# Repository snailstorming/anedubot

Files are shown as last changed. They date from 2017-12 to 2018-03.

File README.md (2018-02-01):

# anedubot
Another educational robot

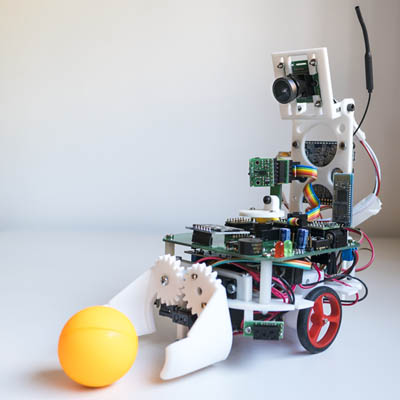
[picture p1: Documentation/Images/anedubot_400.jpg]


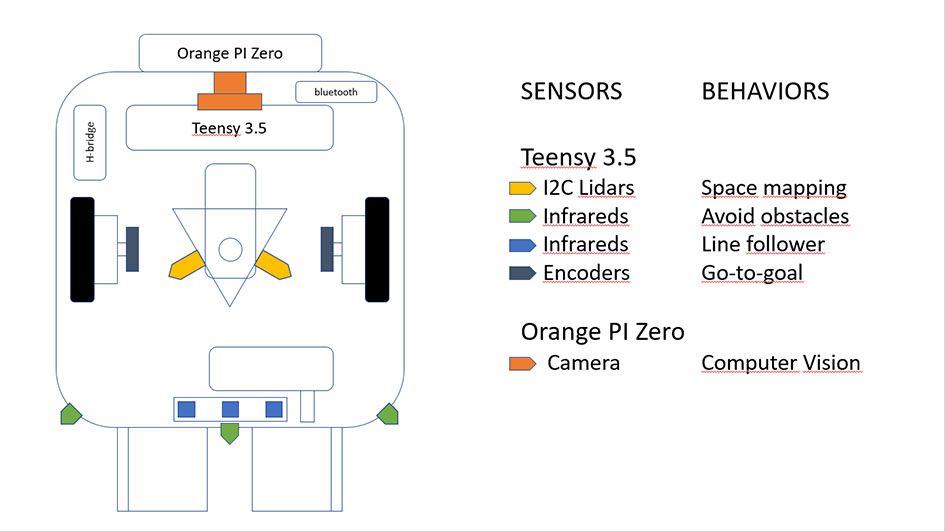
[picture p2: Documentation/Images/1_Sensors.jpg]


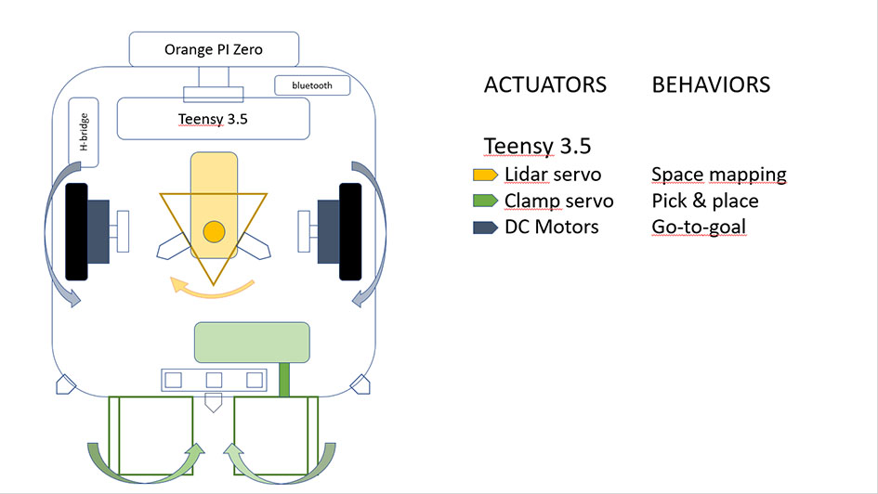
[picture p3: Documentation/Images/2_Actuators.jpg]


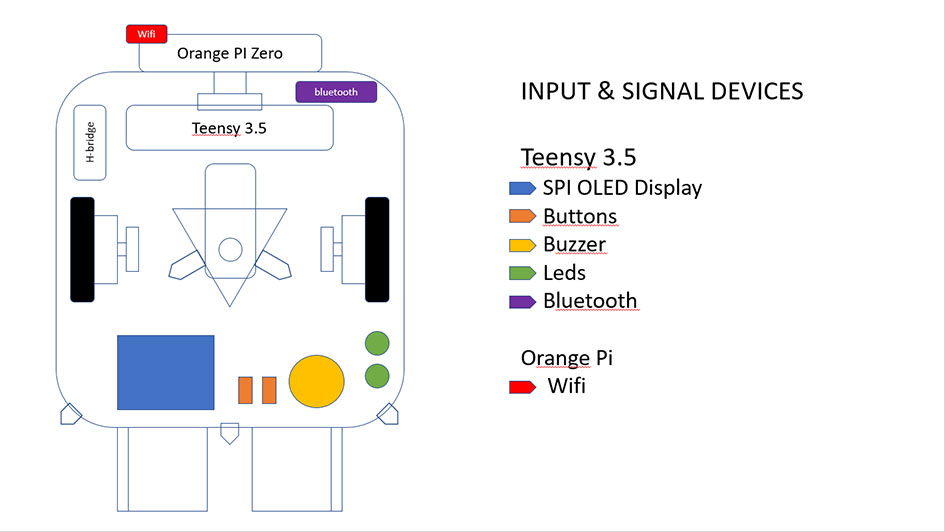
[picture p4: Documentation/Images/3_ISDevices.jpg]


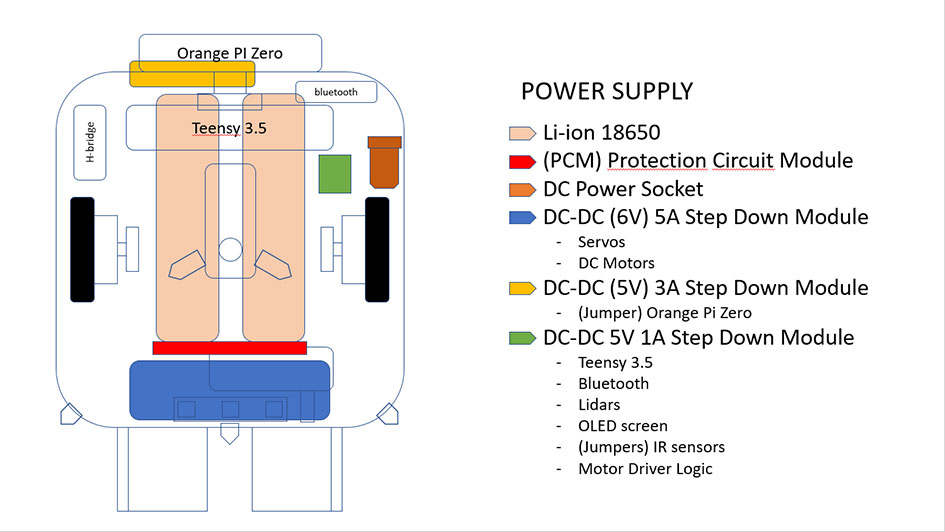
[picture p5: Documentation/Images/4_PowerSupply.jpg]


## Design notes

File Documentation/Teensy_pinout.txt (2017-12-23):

// BUZZER AND RED LED
#define BUZZER_RED_LED  22

//LIDAR SERVO
#define LIDAR_SERVO  8

//CLAMP SERVO
#define CLAMP_SERVO  8

// SPI OLED SCREEN
#define OLED_MOSI   24
#define OLED_CLK   	10
#define OLED_DC    	11
#define OLED_CS    	12
#define OLED_RESET 	25

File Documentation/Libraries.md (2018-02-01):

# EDIT Adafruit_SSD1306 library:
C:\Program Files (x86)\Arduino\hardware\teensy\avr\libraries\Adafruit_SSD1306
```c
   #define SSD1306_128_64
//   #define SSD1306_128_32
//   #define SSD1306_96_16
```

# LIDAR:

[https://github.com/pololu/vl53l0x-arduino](https://github.com/pololu/vl53l0x-arduino)

# MOTORS:

[https://github.com/kevinwchang/r2-dr](https://github.com/kevinwchang/r2-dr)

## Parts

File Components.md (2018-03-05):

Basic model with magnetic encoders:

| ID | Quantity | Description | Link | Price |
|---|---|---|---|---|
|---|---| **Power Supply** |---|---|
| 01 | 2  | 3.7V 18650 Lithium-ion Battery | [RS-AMIDATA](https://ie.rs-online.com/web/p/speciality-size-rechargeable-batteries/7887261/) | 17.18 € |
| 02 | 1 | Battery holder with PCM | [Fasttech](https://www.fasttech.com/p/1279500) | 4 € |
| 03 | 1 | DC-DC 5A Step Down Converter Module | [aliexpress](https://www.aliexpress.com/item/DC-DC-4-5-30V-to-0-8-30V-5A-Step-Down-Converter-Module-Circuit-Voltage/1724909910.html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,searchweb201602_5_10152_10151_10065_10344_10068_10342_10547_10343_51102_10340_10548_10341_10084_10083_10307_10301_10303_10312_10313_10059_10314_10184_10534_100031_10604_10103_10605_10594_10142,searchweb201603_1,ppcSwitch_5&algo_expid=59acf9db-747c-4bae-9396-6da0b7c3cc02-29&algo_pvid=59acf9db-747c-4bae-9396-6da0b7c3cc02&rmStoreLevelAB=5) or [es.aliexpress](https://es.aliexpress.com/item/DC-DC-4-5V-30V-to-0-8V-30V-5A-Step-Down-Power-Apply/32332363457.html) | 4.5€ |
| 04 | 1 | PCB Mount 5.5x2.1mm DC Power Jack Socket | [aliexpress](https://es.aliexpress.com/store/product/10Pcs-PCB-Mount-5-5-x-2-1-mm-Female-DC-Power-Jack-Plug-Socket-Connector/2881256_32816199401.html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,searchweb201602_5_10152_10151_10065_10344_10068_10342_10547_10343_51102_10340_10548_10341_10084_10083_10307_10301_10303_10312_10313_10059_10314_10184_10534_100031_10604_10103_10605_10594_10142,searchweb201603_1,ppcSwitch_5&algo_expid=5eab03d4-3ff3-4e66-bbec-f828e346cfb2-0&algo_pvid=5eab03d4-3ff3-4e66-bbec-f828e346cfb2&rmStoreLevelAB=5) | 1.02 € |
| 05 | 1 | 5.5mm 2.1mm DC 8.4V 1A Power Adapter Supply | [Fasttech](https://www.fasttech.com/p/1284905) | 4 € |
| 06 | 1 | 5V step-up/step-down voltage regulator | [EXP-TECH](https://www.exp-tech.de/en/modules/currentvoltage/4823/pololu-5v-step-up/step-down-voltage-regulator-s7v7f5) | 5€ |
| 07 | 1 | 3.5mm Pitch Terminal Block | [EXP-TECH](https://ie.rs-online.com/web/p/pcb-terminal-blocks/7100444/) | 1.5 €|
|---|---|---|---|---|
| 08 | 1 | Teensy 3.5 | [EXP-TECH](https://www.exp-tech.de/en/platforms/teensy/7786/teensy-3.5) | 25.95 € |
| 09 | 1 | Bluetooth module | [DX](http://www.dx.com/p/jy-mcu-arduino-bluetooth-wireless-serial-port-module-104299) | 4.41 € |
| 10 | 1 | SPI I2C OLED screen | [EBAY](https://www.ebay.com/itm/0-96-I2C-IIC-SPI-Serial-128X64-White-OLED-LCD-LED-Display-Module-for-Arduino-/182546048967) | 3 € |
|---|---| **hardware parts** |---|---|
| 11 | 4 | M2x5 screws (for battery holder) |  |  |
| 12 | 4 | M2 nuts (for battery holder) |  |  |
| 13 | 4 | spacer M3x25 (for main structure) |  |  |
| 14 | 4 | M3x5 screw (for main structure) |  |  |
| 15 | 4 | M3 nuts (for main structure)|  |  |
| 16 | 2 | 12mm Chrome Steel Steel Ball Bearings (for main structure)|  |  | 
|---|---| **Motor parts** |---|---|
| 17 | 2 | mini plastic gearmotor | [EXP-TECH](https://www.exp-tech.de/en/motors/dc-gearmotors/7707/120-1-mini-plastic-gearmotor-hp-offset-3mm-d-shaft-output-extended-motor-shaft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) | 13 € |
| 18 | 1 | magnetic encoders | [EXP-TECH](https://www.exp-tech.de/en/sensors/magnet/7899/magnetic-encoder-pair-kit-for-20d-mm-metal-gearmotors-20-cpr-2.7-18v) | 10 € |
| 19 | 1 | 40mm Wheel | [EXP-TECH](https://www.exp-tech.de/en/accessories/mechanical-components/7847/pololu-wheel-40x7mm-pair-red) | 5.5 € |
| 20 | 1 | Gearmotor bracket | [EXP-TECH](https://www.exp-tech.de/en/motors/dc-gearmotors/6288/pololu-mini-plastic-gearmotor-bracket-pair-wide) | 4.5 € |
| 21 | 1 | motor driver | [EXP-TECH](https://www.exp-tech.de/en/modules/motor-controllers/dc-motors/4805/pololu-drv8835-dual-motor-driver-carrier) | 4.20 € |
|---|---| **Pin headers** |---|---|
| 22 | 1 | Pin headers | [EXP-TECH](https://www.exp-tech.de/en/accessories/connectors/7921/1x40-pin-break-away-headers-straight-10-pack) | 5 € |
| 23 | 1 | Short pin headers | [EXP-TECH](https://www.exp-tech.de/en/accessories/connectors/6759/2mm-pitch-40-pin-break-apart-male-headers-pack-of-5) | 3.5 € |
| 24 | 1 | Short female socket headers | [EXP-TECH](https://www.exp-tech.de/en/accessories/connectors/6760/2mm-pitch-25-pin-female-socket-headers-pack-of-5) | 4 € |
| 25 | 1 | 1x4 female socket headers | [RS-AMIDATA](https://ie.rs-online.com/web/p/pcb-sockets/8282067/) | 1 € |
|---|---| Other parts |---|---|
| 26 | 1 | red led | [RS_AMIDATA](https://ie.rs-online.com/web/p/visible-leds/2285988/) | 1.3 € |
| 27 | 1 | green led | [RS_AMIDATA](https://ie.rs-online.com/web/p/visible-leds/2286004/) | 1.3 € |
| 28 | 1 | Piezo buzzer | [RS-AMIDATA](https://ie.rs-online.com/web/p/piezo-buzzer-components/5358253/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) | 2.5 € |
| 29 | 1 | resitor 220ohms | [RS-AIMDATA](https://ie.rs-online.com/web/p/through-hole-fixed-resistors/7077612/) | 1.5 €|
| 30 | 1 | resitor 22Kohms | [RS-AIMDATA](https://ie.rs-online.com/web/p/through-hole-fixed-resistors/7077779/) | 1.5 €|
| 31 | 1 | jumpers | [RS-AMIDATA](https://ie.rs-online.com/web/p/jumpers-shunts/6742397/) | 1 € |
| 32 | 1 | mini pushbutton switch | [RS-AMIDATA](https://www.exp-tech.de/en/accessories/buttonsswitches/5434/mini-pushbutton-switch-pcb-mount-2-pin-spst-50ma-5-pack) | 1 € |
| 33 | 1 | Slide Switch | [RS-AMIDATA](https://www.exp-tech.de/en/accessories/buttonsswitches/5114/breadboard-friendly-spdt-slide-switch) | 1.5 € |
| 34 | 1 | Capacitor 100uF | [RS-AMIDATA](https://ie.rs-online.com/web/p/aluminium-capacitors/7110842/) | 2 € |
|---|---| **PCB** |---|---|
| 35 | 1 | PCB|[PCB Way](https://www.pcbway.com/)| 15€|
|---|---| **3D Frame** |---|---|
| 36 | 1 | Base.scad |[3DHUBS](https://www.3dhubs.com)| 12€|
|---|---| **Total price** |---|---|
|---|---|---|---| **163 €** |

Pick & place Kit:

| ID | Quantity | Description | Link | Price |
|---|---|---|---|---|
| 37 | 1 | Servo motor | [EBAY](https://www.ebay.com/itm/232208650170) | 6 € |
|---|---| ***3D Frame*** |---|---|
| 38 | 1 | Clamp |[3DHUBS](https://www.3dhubs.com)|  € |
| 39 | 1 | Clamp_servo_support |[3DHUBS](https://www.3dhubs.com)| 8 € |
|---|---| ***hardware parts*** |---|---|
| 40 | 2 | M3x20 screw (for servo bracket) |  |  |
| 41 | 2 | M3x10 screw (for servo) |  |  |
| 42 | 1 | M3x12 screw (for right clamp) |  |  |
| 43 | 2 | 2x8 wood screws (for left clamp) |  |  |
| 44 | 4 | M3 nuts |  |  |
|---|---| ***Balls*** |---|---|
| 45 | ? | colored ping pong balls |  |  |
| 46 | 3 | 12mm Chrome Steel Steel Ball Bearings (for main structure)|  |  |

Avoid Obstacles & Line Follower Kit:

| ID | Quantity | Description | Link | Price |
|---|---|---|---|---|
| 47 | 1 | Female-Male Jumper Wires | [EXP-TECH](https://www.exp-tech.de/en/accessories/cables/jumper-wires/7797/premium-female/male-extension-jumper-wires-40-x-6-150mm) | 4.5 € |
| 48 | 5 | M2x5 screw  |  |  |
| Avoid Obstacles |---|---|---|
| 49 | 2 | Digital Distance Sensor 5cm | [EXP-TECH](https://www.exp-tech.de/en/sensors/distanceapproximation/4905/pololu-carrier-with-sharp-gp2y0d805z0f-digital-distance-sensor-5cm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) | 6 € |
| 50 | 1 | Digital Distance Sensor 10cm | [EXP-TECH](https://www.exp-tech.de/en/sensors/distanceapproximation/4906/pololu-carrier-with-sharp-gp2y0d810z0f-digital-distance-sensor-10cm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) | 6 € |
|---|---| Line Follower |---|---|
| 51 | Digital Sensor Array | [EXP-TECH](https://www.exp-tech.de/en/sensors/distanceapproximation/5235/qtr-3rc-reflectance-sensor-array) | 5 € |
| 52 | 2 | M2 nuts |  |  |

Space Mapping Kit:

| ID | Quantity | Description | Link | Price |
|---|---|---|---|---|
| 53 | 1 | Servo motor | [HOBBYKING](https://hobbyking.com/es_es/power-hd-1900a-servo-1-7kg-0-08sec-9g.html) | 4€ |
| 54 | 2 | Time-of-Flight Distance Sensor | [EXP-TECH](https://www.exp-tech.de/en/sensors/distanceapproximation/7557/pololu-vl53l0x-time-of-flight-distance-sensor-carrier-with-voltage-regulator-200cm-max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) | 30 € |
| 55 | 2 | Ribbon Crimp Connector - 6-pin (2x3, Female) | [RS_AMIDATA](https://ie.rs-online.com/web/p/idc-connectors/8323648/) | 1.5 € |
| 56 | 2 | 2x3 Pin Shrouded Header | [EXP-TECH](https://www.exp-tech.de/en/accessories/connectors/4606/2x3-pin-shrouded-header?number=EXP-R05-210) | 1.5 € |
| 57 | 1 | Ribbon Cable - 6 wire | [EXP-TECH](https://www.exp-tech.de/en/accessories/cables/sonstige/5822/ribbon-cable-6-wire-15ft) | 3.5 € |
|---|---| **PCB** |---|---|
| 58 | 1 | PCB|[PCB Way](https://www.pcbway.com/)| 5€|
|---|---| **3D Frame** |---|---|
| 59 | 1 | lidar_support |[3DHUBS](https://www.3dhubs.com)| 5 € |
|---|---| **hardware parts** |---|---|
| 60 | 1 | M3x10 screw |  |  |
| 61 | 1 | M3 nuts |  |  |
| 62 | 2 | 2x8 wood screws |  |  |
| 63 | 2 | M2x5 screw |  |  |
| 64 | 2 | M2 nuts |  |  |

Computer Vision Kit:

| ID | Quantity | Description | Link | Price |
|---|---|---|---|---|
| 65 | 1 | (512 MB) Orange Pi Zero | [ALIEXPRESS](https://es.aliexpress.com/store/product/New-Orange-Pi-Zero-H2-Quad-Core-Open-source-512MB-development-board-beyond-Raspberry-Pi/1553371_32761500374.html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) | 11.5 € |
| 66 | 1 | 32GB MircoSD | Amazon? | 17 € ? |
| 67 | 1 | ELP Mjpeg 640x480 VGA USB Camera | [AMAZON](https://www.amazon.es/dp/B017GXPULW/ref=pe_3310721_189395781_TE_dp_1) | 35 € |
| 69 | 1 | Type A USB Connector Plug | [RS-AMIDATA](https://ie.rs-online.com/web/p/type-a-usb-connectors/6742268/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) | 3.5 € |
| 70 | 1 | DC-DC 3A Step Down Converter Module | [DEAL-EXTREME](http://www.dx.com/p/48v-step-down-module-dc-dc-4-5-60v-switching-power-supply-blue-434337) | 3.5 € |
| 71 | 10 | M3x10 screw |  |  |
| 72 | 10 | M3 metal nuts |  |  |
| 73 | 6 | M3 platic nuts |  |  |
| 74 | 4 | M2x8 screw |  |  |
| 75 | 4 | M2 metal nuts |  |  |
|---|---| **3D Frame** |---|---|
| 76 | 1 | opy_support | [3DHUBS](https://www.3dhubs.com) | € |
| 77 | 1 | camera_support | [3DHUBS](https://www.3dhubs.com) | 8 € |

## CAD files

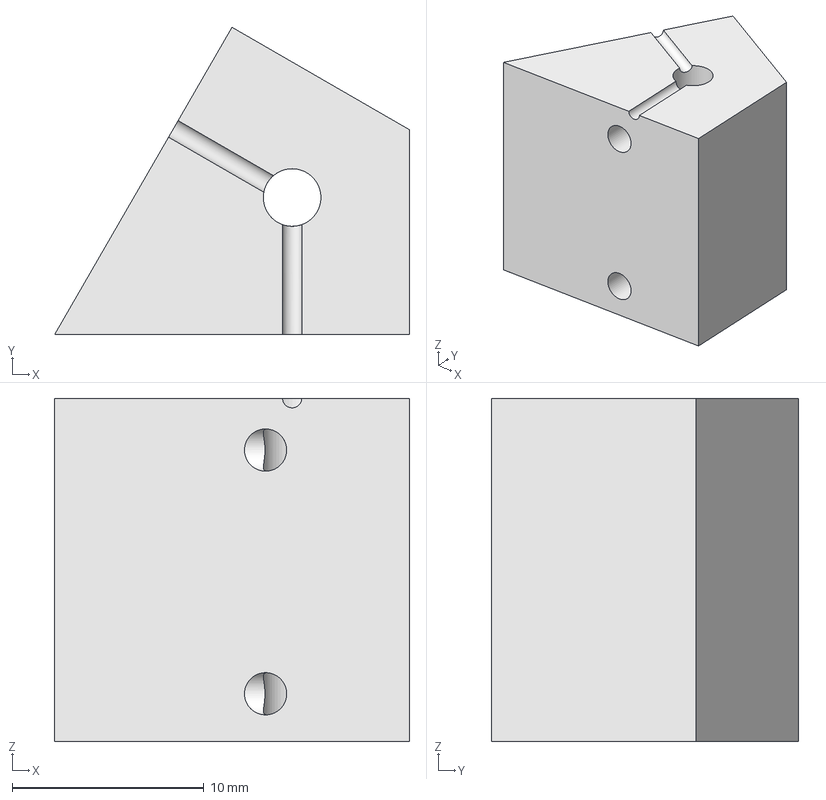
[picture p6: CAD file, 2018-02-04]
Frame/lidarArrow.FCStd
18.5 x 16.0 x 17.9 mm

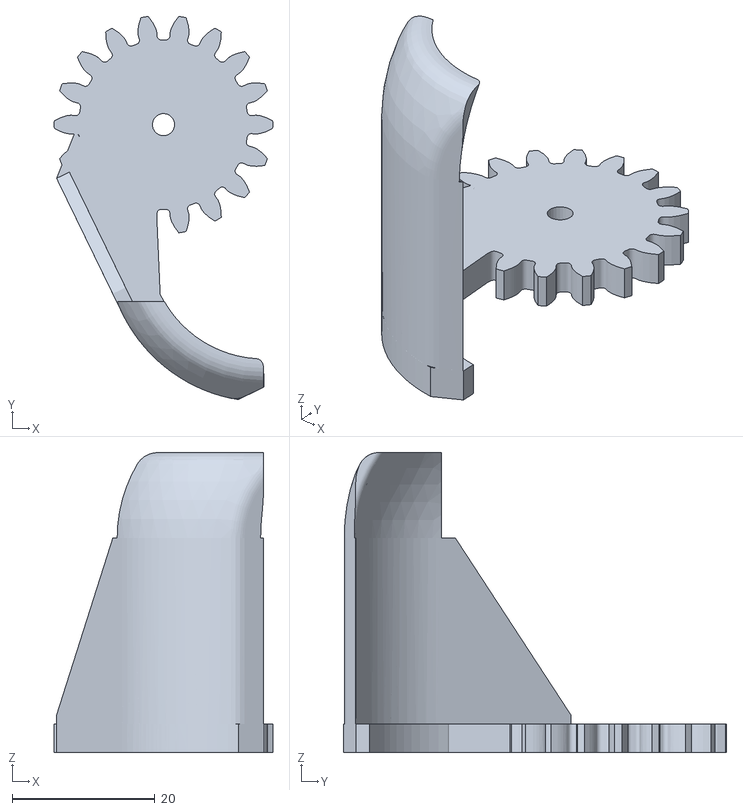
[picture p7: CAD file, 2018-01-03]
Frame/stl/right_clamp.stl
30.6 x 53.7 x 42.0

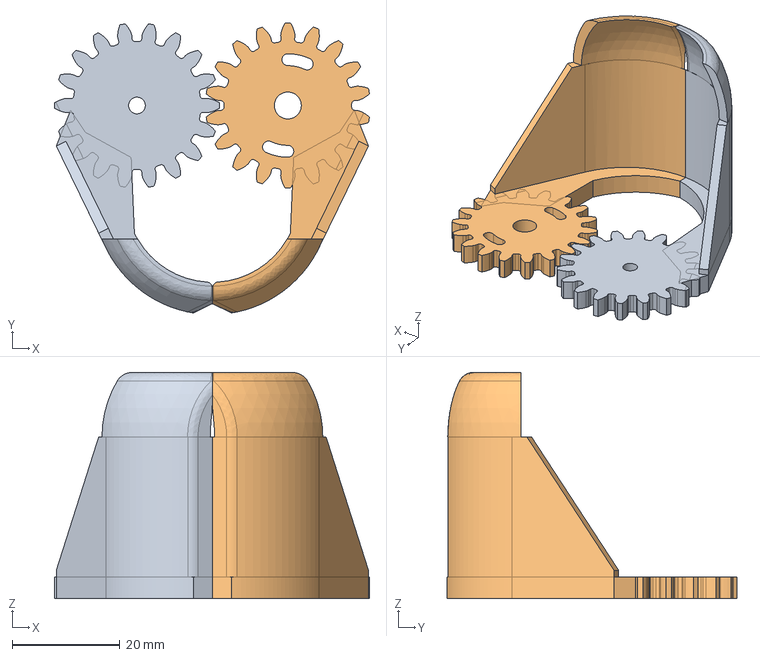
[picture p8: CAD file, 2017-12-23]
Frame/clamp.FCStd
58.5 x 53.8 x 42.0 mm

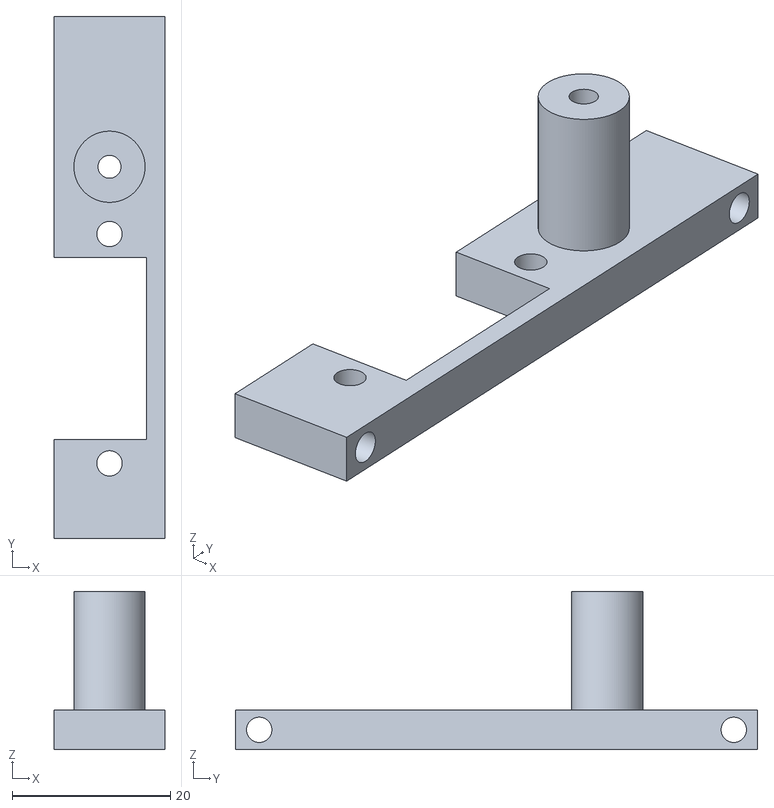
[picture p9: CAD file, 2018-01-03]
Frame/stl/clamp_servo_support.stl
14.0 x 66.0 x 20.0

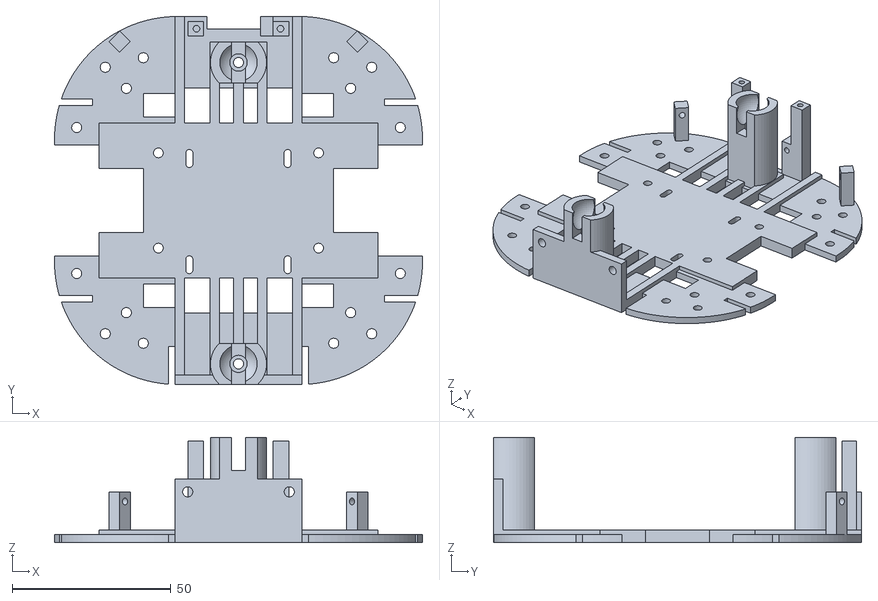
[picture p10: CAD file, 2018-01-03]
Frame/stl/Base.stl
116.0 x 116.0 x 33.2

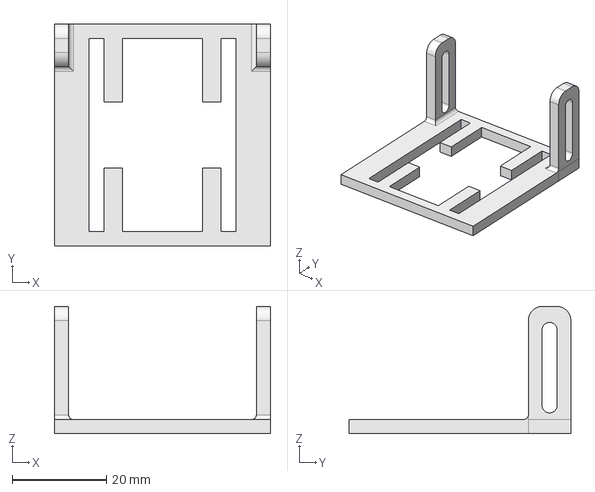
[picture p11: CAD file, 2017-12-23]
Frame/camera_support.fcstd
45.8 x 47.0 x 27.0 mm

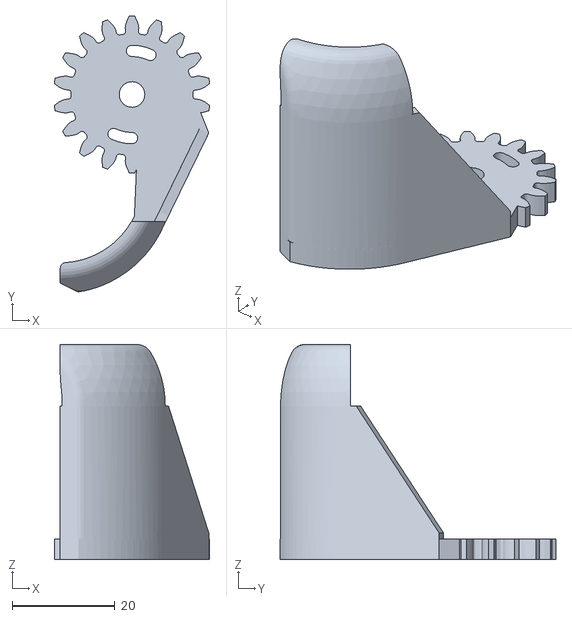
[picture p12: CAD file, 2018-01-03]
Frame/stl/left_clamp.stl
30.3 x 53.8 x 42.0

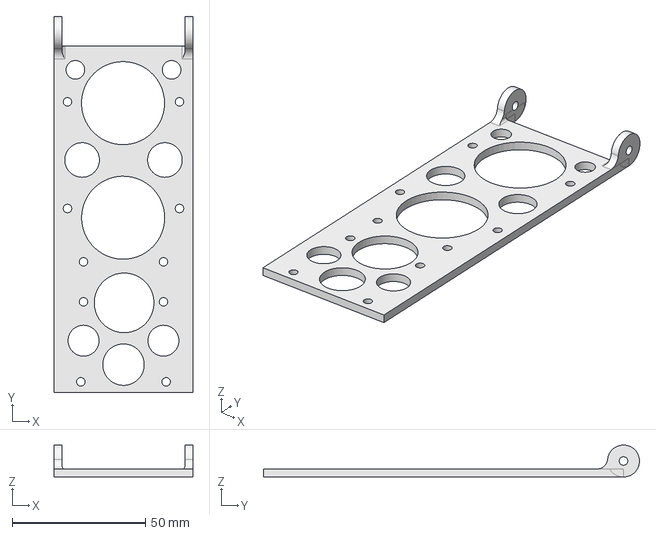
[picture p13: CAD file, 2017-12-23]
Frame/opy_support.fcstd
52.0 x 141.0 x 12.0 mm

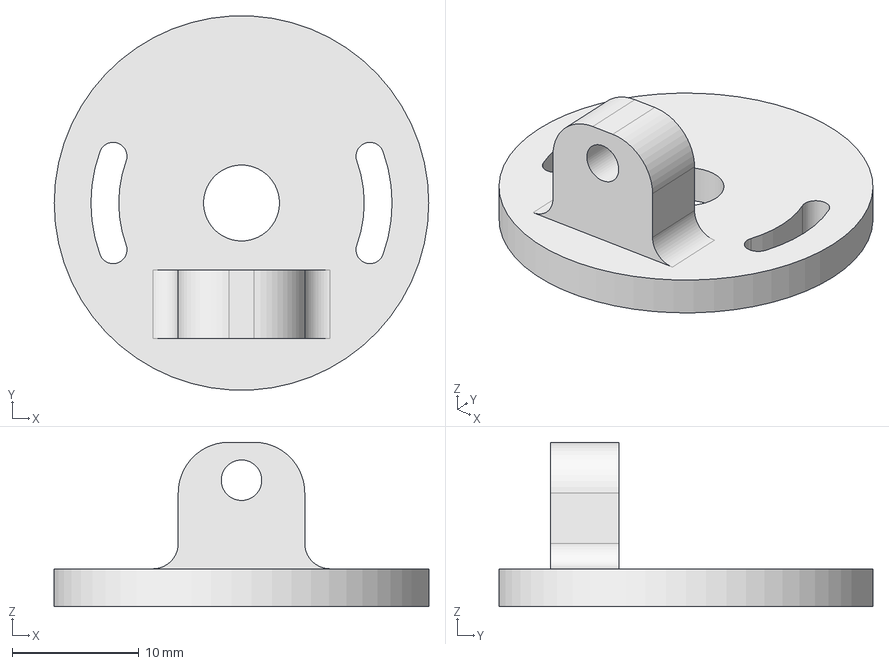
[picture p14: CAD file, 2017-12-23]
Frame/lidar_support.fcstd
29.6 x 29.6 x 13.0 mm

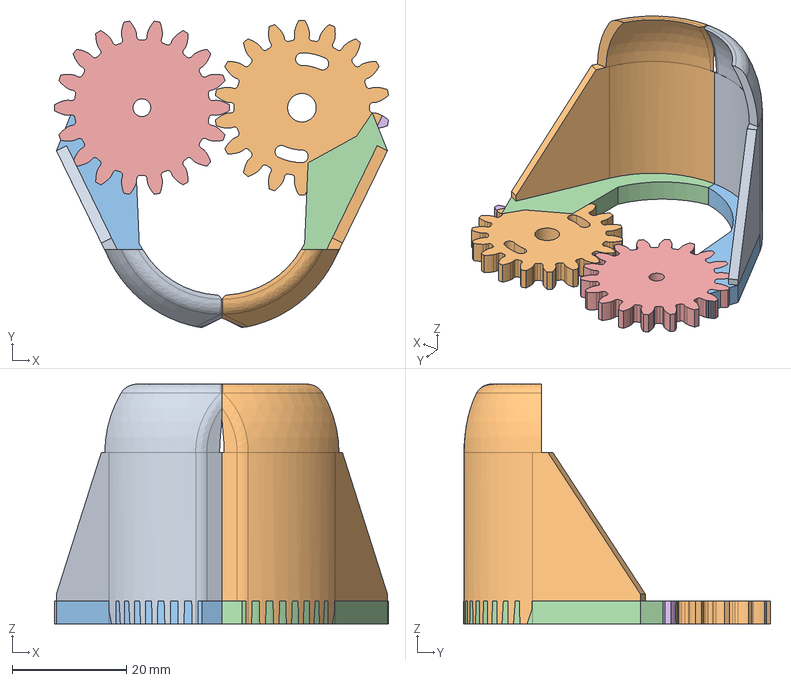
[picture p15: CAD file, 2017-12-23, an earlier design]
Frame/clamp_old_version.FCStd
58.5 x 53.8 x 42.0 mm
Pad008 (Mirror #3)

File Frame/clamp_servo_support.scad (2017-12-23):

difference(){
    union(){
        cube([14,66,5], center = true);
        translate ([0,14,-2.5])
            cylinder(h=5+14+1, d= 9, $fn=100);
    }
    
    rotate([0,90,0])
    translate([0,30,-8])
        cylinder(d=3.2, h = 16, $fn=100);
    
    mirror([0,1,0])
        rotate([0,90,0])
        translate([0,30,-8])
            cylinder(d=3.2, h = 16, $fn=100);
    
    translate([(-14+11.7)/2-.5,-23/2+2+0.5,0])
    cube([11.7+1,23,7], true);

    translate([0,19.5-14,-3.5])
    cylinder(h=7, d= 3.2, $fn=100);
    
    translate([0,-9.5-14,-3.5])
    cylinder(h=7, d= 3.2, $fn=100);
    
    translate ([0,14,-2.5-1])
        cylinder(h=5+14+2+1, d= 2.9, $fn=100);
}

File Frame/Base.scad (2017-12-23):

use <castor.scad>

//Base constants
thickness=3;

//Castor constants
BallSize = 11.9;
TotalHeight = 28.7-0.1+7.4/2+1.7/2;
BallProtrude = .25;
CastorHeigh = TotalHeight - (BallSize*BallProtrude);
//END Castor constants

module only_x(){
    children();
    mirror([0,1,0])
        children();
}

module only_y(){
    children();
    mirror([1,0,0])
        children();
}
module mirror_x_y(){
    only_x(){
        children();
        mirror([1,0,0])
            children();
    }
}

//line follower and front ir support
translate([-31.9/2,50.3,0]){
    difference(){
        union(){
            translate([0,1.5,0])
                cube([31.9,7.7-3,TotalHeight-2+1.7/2]);
            translate([20,2,0])
            cube([6.8,5.7,TotalHeight-2]);
        }
        
        translate([2.7,7.7/2,30.3-10])
            cylinder($fn = 100,h=50, d=2.1);
            
        translate([-2.7+31.9,7.7/2,30.3-10])
            cylinder($fn = 100,h=50, d=2.1);

        translate([31.9/2+9,10,13])
        rotate([90,0,0])
            cylinder($fn = 100,h=15, d=2.1);
        
        translate([(31.9-20)/2-1,-1,-1])
            cube([31.9-20+5+1,7.7+2,TotalHeight]);
        translate([(31.9)/2-6,-1,-1+17])
            cube([31.9-20+5,7.7+2,TotalHeight]);
    }
}



union(){
    
    //main Y beams
    
    translate([-1.5,-93/2,0])
        cube([3,93-8,4]);

    only_y(){
        
    translate([6,-116/2,0])
        cube([3,116-8,4]);
    translate([6+6+5,-116/2,0])
        cube([3,116,4]);
        
    }

difference(){
    union(){
        //Without mirrors elements
        
        // main structure
        translate([0,0,1.25]){
            cube([116/3,116,2.5],true);
            cube([116,116/3,2.5],true);
        }
        
        //main X beams        
        translate([-30-14,-23.5-1,0])
            cube([60+28,47+2,4]);

        //Castor supports
        translate([0,-51.5,0])
            castor(BallSize,TotalHeight + thickness,false);

        translate([0,43.5,0])
            castor(BallSize,TotalHeight + thickness,false);       
        //END Without mirrors elements
    
        only_x(){
          
        }
            
        only_y(){
           // 5cm IR supports
           rotate([0,0,45]){
                translate([-31.9/2,50.3+7.3,0]){
                    difference(){
                        translate([20+2.5,2,0])
                            cube([4.8,5.7-1,16]);

                        translate([31.9/2+9,10,13])
                            rotate([90,0,0])
                            cylinder($fn = 100,h=15, d=2.2);
                    }
                }
           }

        //orange pi support
        translate([-20,-58,0])
            cube([15,3,20]);

         
        }
        
        
        mirror_x_y(){

        // main structure            
        translate([116/6,116/6,0]){
            cylinder($fn = 100,h=2.5, d=116*2/3);
        }
      
        }

    } //END union

    // Difference elements

        //Without mirrors elements
    
        //Castor holes
        translate([0,43.5,-1]){
            cylinder($fn = 20,h=40, d=3.2);
            
            translate([0,0,3])
                cylinder($fn = 20,h=40, d=5.5);
            }

            translate([0,-51.5,-1]){
                cylinder($fn = 20,h=40, d=3.2);
            translate([0,0,3])
                cylinder($fn = 20,h=40, d=5.5);
        }
        
        // line follower wires holes
        translate([-10,54,-1])
        cube([20,5,6]);
        
        //END Without mirrors elements
    
    only_x(){

       
        translate([0,30,0]){
            cube([40,15-4,7], true);
            cube([60,15/2,7], true);
        }
       
        translate([-5,116/2,-2])
            cube([10,10,TotalHeight + thickness+5]); 

    }
    only_y(){
        //Motor holes
        translate([30+7,0,0]){
            cube([14.2,20.2,10], true);    
                translate([6.95+10,0,0])
                    cube([20,35,10], true);    
        }
        //wire holes
        translate([12+8,-46-20,-1])
            cube([2,20,7]);
        
        //battery holder holes
        translate([31/2,11.5,-1]){
            cylinder($fn = 20,h=7, d=2.2);
            translate([0,1.75,0])
                cube([2.2,1.5+2.5,20], true);
            translate([0,3.5,0])
                cylinder($fn = 20,h=7, d=2.2);
        }
        
        translate([31/2,-11.5-7,-1]){
            cylinder($fn = 20,h=7, d=2.2);
            translate([0,-1.75,0])
                cube([2.2,1.5+2.5,20], true);
            translate([0,-3.5,0])
                cylinder($fn = 20,h=7, d=2.2);
        }
        
        //orange pi support holes
        rotate([90,0,0])
           translate([-16,16,50])
            cylinder($fn = 100,h=10, d=3.2);
         
    }
    mirror_x_y(){


        translate([46,30,-1])
            cube([20,2,7]);
        
        //holes near motors
        translate([51,23,-1])
            cylinder($fn = 20,h=40, d=3.2);

        // PCB support            
        rotate([0,0,45])
        translate([0,50,-1])
            cylinder($fn = 20,h=40, d=3.2);      
    
        translate([42,42,-1])
            cylinder($fn = 20,h=40, d=3.2);      
        
        //clamp servo support holes
        translate([30,116/2-13,-1])
            cylinder($fn = 20,h=40, d=3.2)
        
        //wheels frame holes
        translate([51,23,-1])
            cylinder($fn = 20,h=40, d=3.2);      
        
        //motor bracket holes
        translate([25.25,15,-1])
            cylinder($fn = 20,h=7, d=3.1);

    }

}//END difference
}

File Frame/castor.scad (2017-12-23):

// I use PLA and G16 Hardened Carbon Steel Bearing Balls 12mm.
// I used this series in order to check the best BallSize value.
// The BallSize value is at the bottom of every piece.

$fn =  50;

//user adjustable parameters
WallThickness = 2.25; //thickness of the retaining wall
//BallSize = 11.9;  //diameter of  your ball bearing.
BallSize = 11.6;  //diameter of  your ball bearing.
Airgap = .65;  // Gap between ball and wall
BallProtrude = .25; //percentage of ball radius sticking out 
WheelDiameter = 56;  //what size wheels you will use.


for (i=[0:4]){
    BallSize=BallSize + 0.1*i;
    TotalHeight = 23;

    translate ([i*30,0,0])
        castor(BallSize,TotalHeight,true);
}

module castor(BallSize, TotalHeight, text_bsize){
    cylrad = (BallSize/2) + WallThickness + Airgap;
    echo (cylrad);
    
    difference (){
        rotate( a = [0,0,90] ){
            difference(){ 
                cylinder(r1 = cylrad , r2 = cylrad, TotalHeight - (BallSize*BallProtrude));
    
                translate([0,0,TotalHeight - BallSize/2]) 
                    cube(size = [cylrad*2+5, cylrad/2, BallSize*1.25], center = true );
    
                translate([0,0,TotalHeight - (BallSize/2)]) 
                    sphere (BallSize/2+Airgap, $fa=5, $fs=0.1);
                
                if (text_bsize == true){
                    rotate([0,180,0])
                        translate ([0,0,-1])
                            linear_extrude(2)text(text=str(BallSize), size = 5,halign = "center", valign = "center");
                }
            }
        }
        rotate([0,0,0])
            translate ([-cylrad-1,6.5,-1])
                cube ([cylrad*2+2,10,TotalHeight+2]);
        rotate([0,0,180])
            translate ([-cylrad-1,6.5,-1])
                cube ([cylrad*2+2,10,TotalHeight+2]);
    }

}

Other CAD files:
Frame/stl/camera_support.stl
Frame/stl/lidarArrow.stl
Frame/stl/lidar_support.stl
Frame/stl/opy_support.stl

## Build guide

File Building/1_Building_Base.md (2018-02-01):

# DC Motors

Compontents ID: 17-21 & 24 (Short female socket headers 1x6)

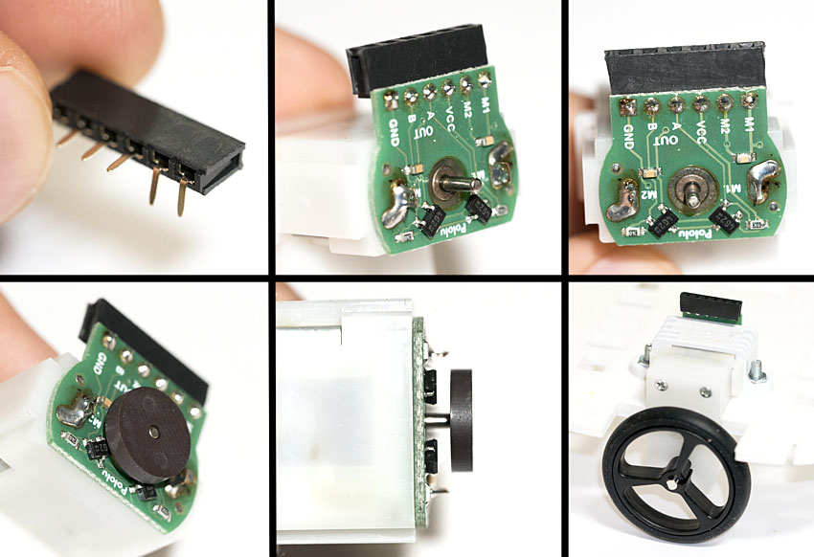
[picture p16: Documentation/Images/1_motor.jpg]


# Base

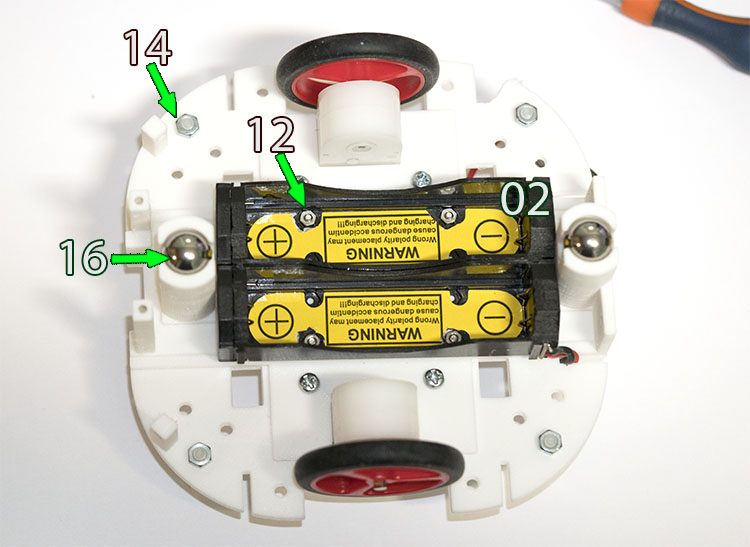
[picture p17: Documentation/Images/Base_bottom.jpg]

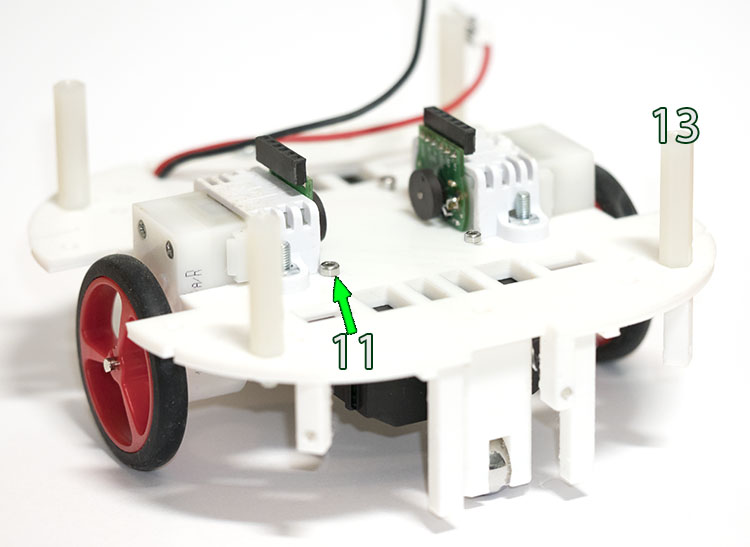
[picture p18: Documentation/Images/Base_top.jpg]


# Clamp

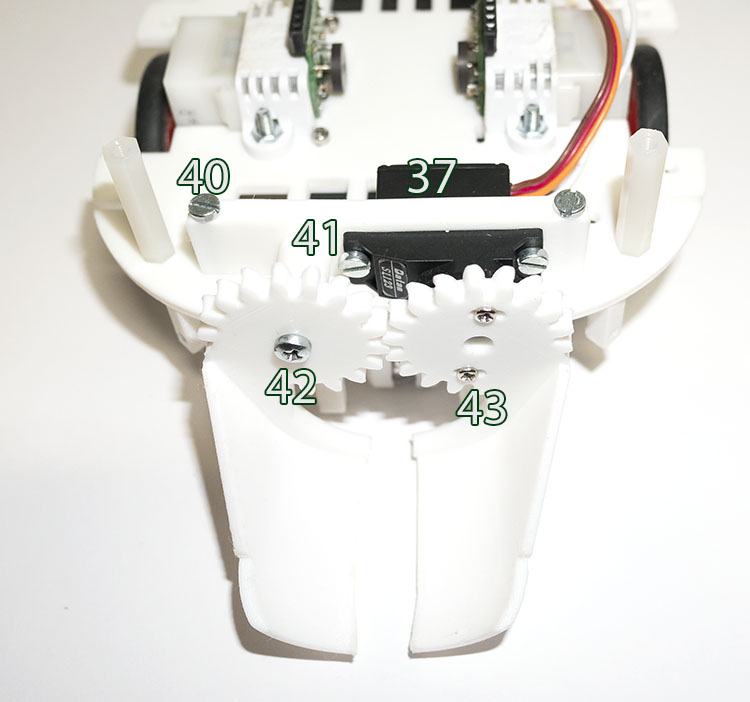
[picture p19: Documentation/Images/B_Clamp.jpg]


# Balls

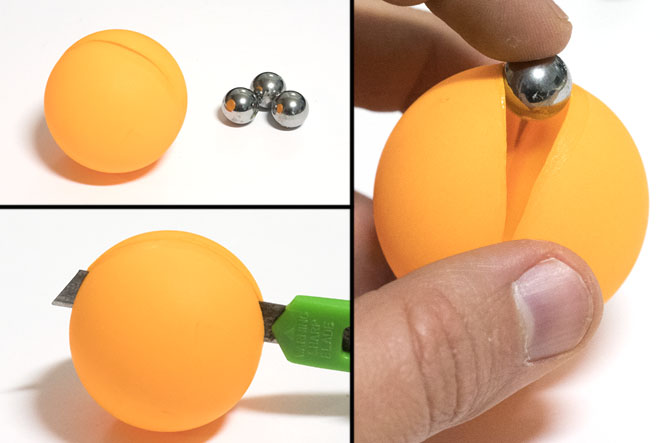
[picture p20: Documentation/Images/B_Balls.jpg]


# Infrared sensors

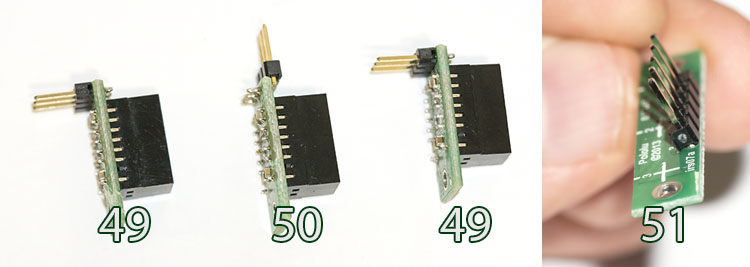
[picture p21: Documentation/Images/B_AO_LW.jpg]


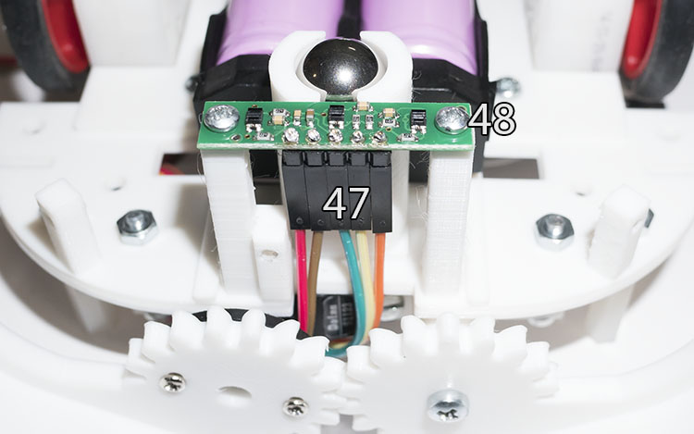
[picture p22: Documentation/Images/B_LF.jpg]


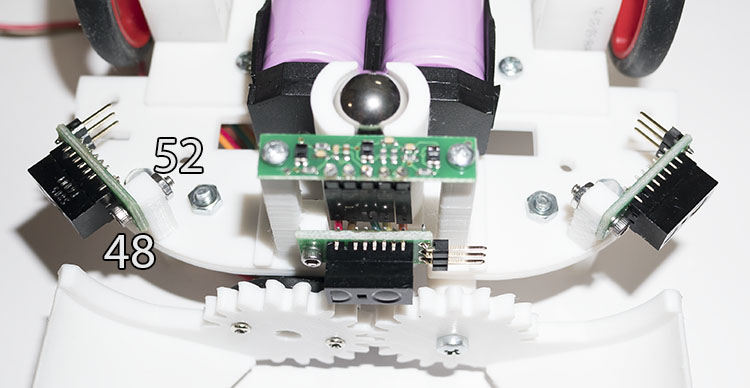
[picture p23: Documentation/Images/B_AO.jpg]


# Wires

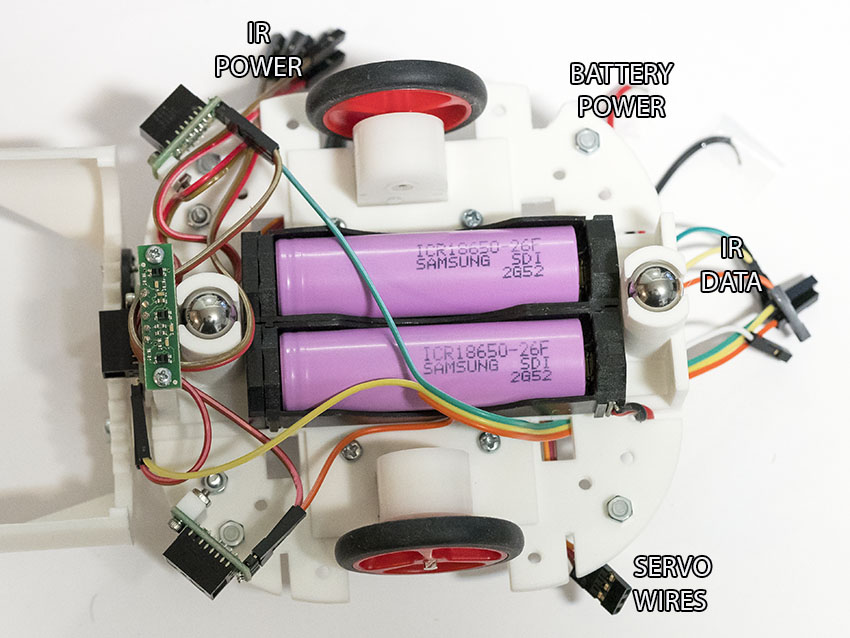
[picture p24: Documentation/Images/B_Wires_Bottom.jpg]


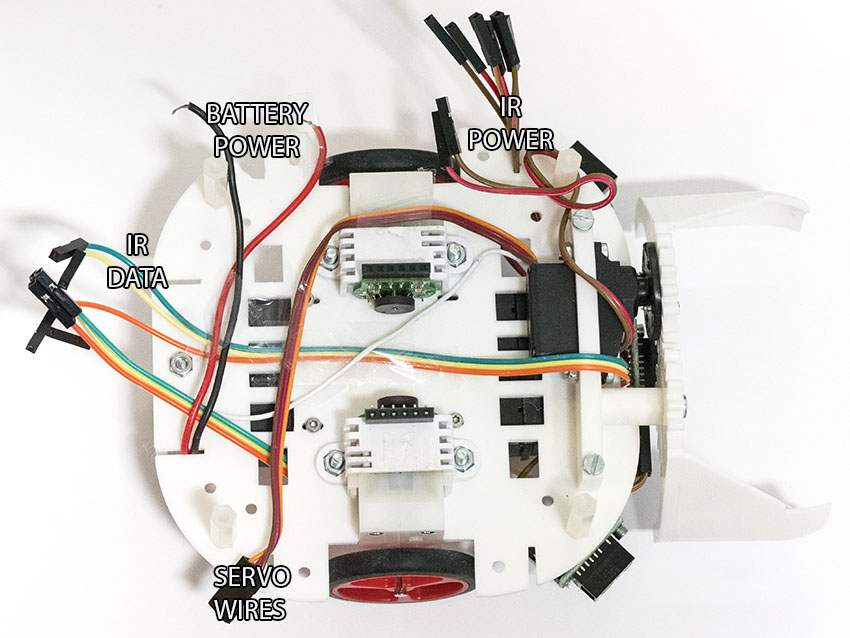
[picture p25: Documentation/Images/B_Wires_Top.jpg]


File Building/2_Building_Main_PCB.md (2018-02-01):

# Front main PCB:

| ID_PCB | ID_Component | Description | Size |
|---|---|---|---|
| D1 | 26 | Red led | 1 |
| D2 | 27 | Green led | 1 |
| R1 | 30 | 22K resistor | 1 |
| R2 | 29 | 220 resistor | 1 |
| BZ1 | 28 | Buzzer | 1 |
| SW1 | 33 | Slide switch | 1 |
| Sw2 | 32 | Push button | 1 |
| Sw3 | 32 | Push button | 1 |
| C1 | 34 | 100uF capacitor | 1|
| C2 | 34 | 100uF capacitor | 1|
| CONN1 | 04 | Power jack socket | 1 |
| REG1 | 06 | 5V 1A voltage regulator | 1 |
| O1 | 24 | Short female socket headers | 1x6 |
| P1 | 24 | Short female socket headers | 1x7 |
| P2 | 24 | Short female socket headers | 1x7 |
| P3 | 24 | Short female socket headers | 1x15 |
| P4 | 24 | Short female socket headers | 1x7 |
| P5 | 24 | Short female socket headers | 1x24 |
| P6 | 25 | female socket headers | 1x4 |
| P7 | 22 | Pin headers | 1x3 |
| P8 | 22 | Pin headers | 1x3 |
| P9 | 56 | Shrouded Header | 1 |
| J1 | 22 | Pin headers | 1x2 |
| J2 | 22 | Pin headers | 1x2 |
| J3 | 22 | Pin headers | 1x2 |
| J4 | 22 | Pin headers | 1x2 |

> **WARNING** Be careful to observe D1, D2, BZ1, C1,C2, REG1 and P9 polarity. 

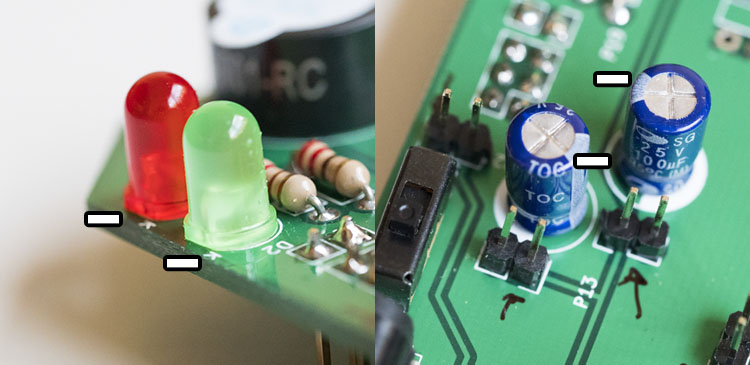
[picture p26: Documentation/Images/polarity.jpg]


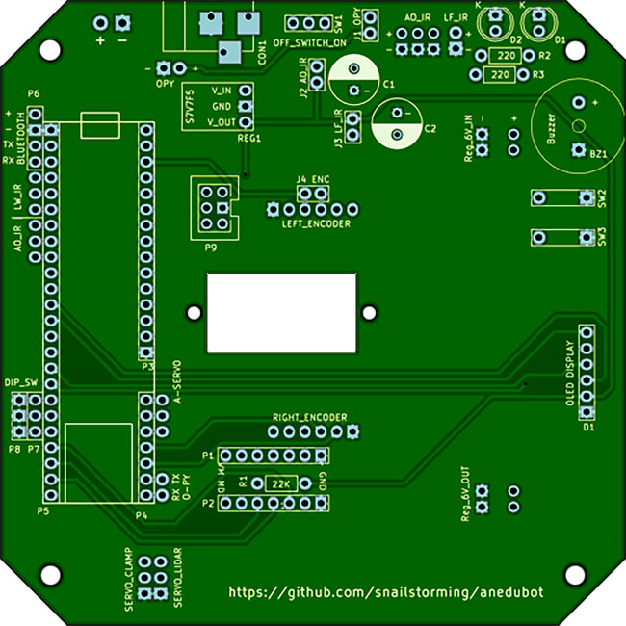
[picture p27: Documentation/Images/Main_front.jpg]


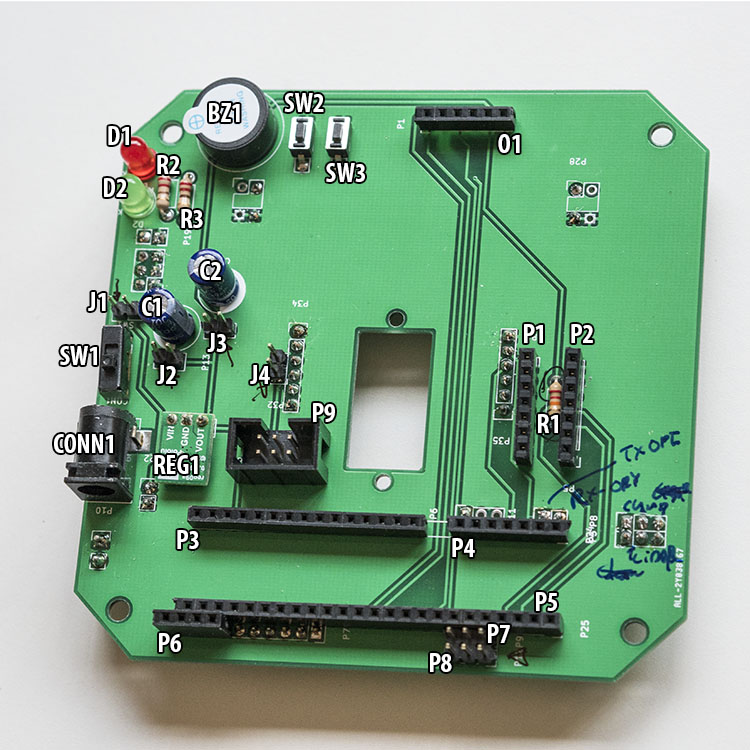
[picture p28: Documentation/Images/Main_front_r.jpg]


# Back main PCB:

| ID_PCB | ID_Component | Description | Size |
|---|---|---|---|
| P10 | 22 | Pin headers | 1x2 |
| P11 | 22 | Pin headers | 2 x 1x3 |
| P12 | 22 | Pin headers | 1x2 |
| P13 | 07 | 3.5mm Pitch Terminal Block | 1 |
| P14 | 24 | Short female socket headers | 1x3 |
| P15 | 24 | Short female socket headers | 1x3 |
| P16 | 22 | Pin headers | 1x6 |
| P17 | 22 | Pin headers | 1x6 |
| P18 | 22 | Pin headers | 1x3 |
| P19 | 22 | Pin headers | 1x3 |
| P20 | 22 | Pin headers | 1x1 |
| P21 | 22 | Pin headers | 1x2 |
| P22 | 22 | Pin headers | 1x6 |

P14 & P15 detail:

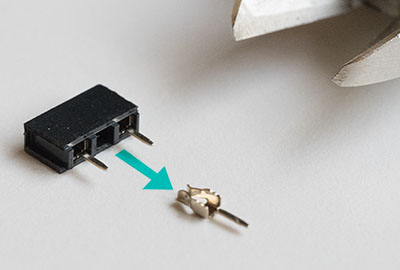
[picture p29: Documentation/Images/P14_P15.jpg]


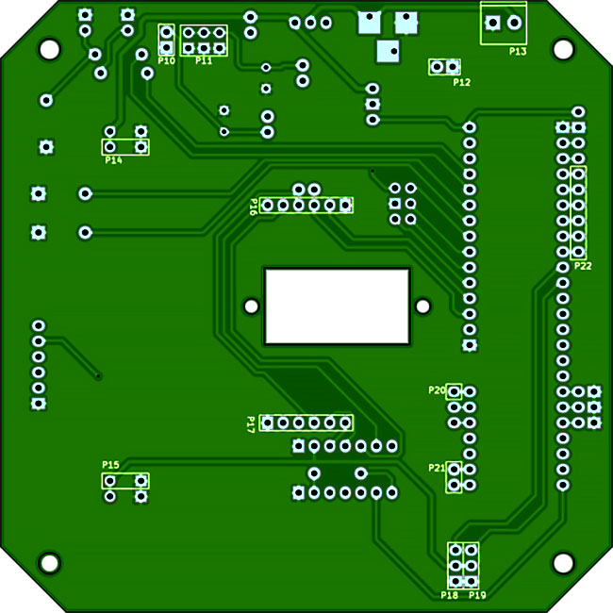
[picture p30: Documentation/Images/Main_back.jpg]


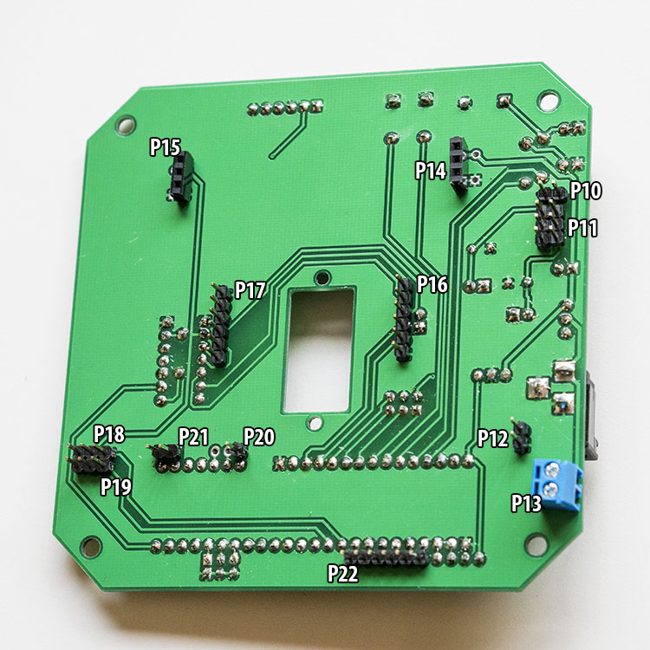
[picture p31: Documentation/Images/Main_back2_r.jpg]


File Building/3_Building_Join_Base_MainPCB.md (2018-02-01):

# Main board bottom

> **Video:** Solding pin headers in Regulator

IMAGE ALT TEXT HERE (http://www.youtube.com/watch?v=kZGVo9eDCLo)

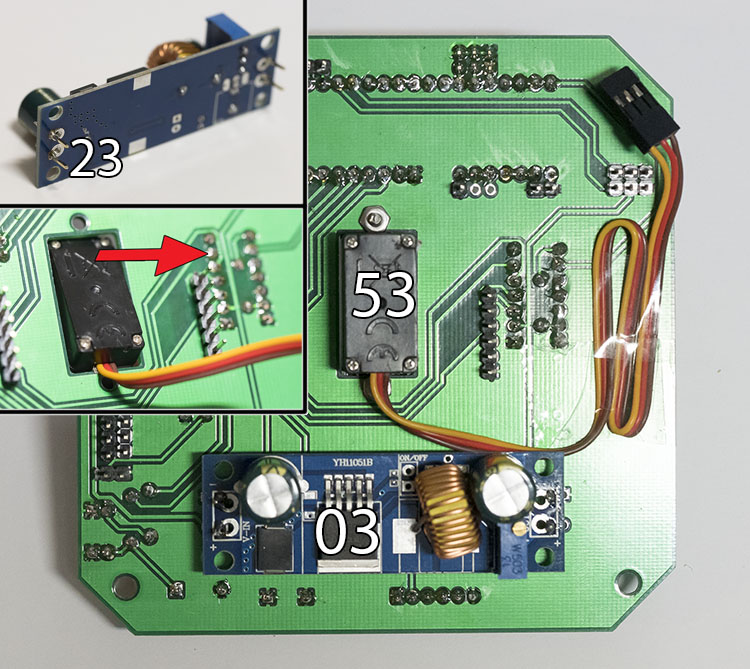
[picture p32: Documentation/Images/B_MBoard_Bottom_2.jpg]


# Main board top

Solder short pin headers (component ID:23) to oled screen, motor driver and teensy 3.5:

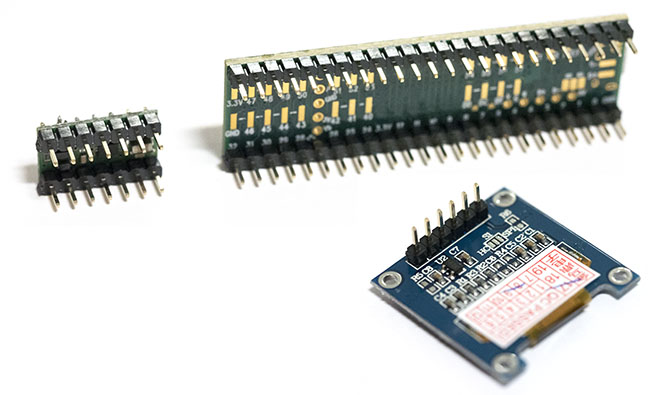
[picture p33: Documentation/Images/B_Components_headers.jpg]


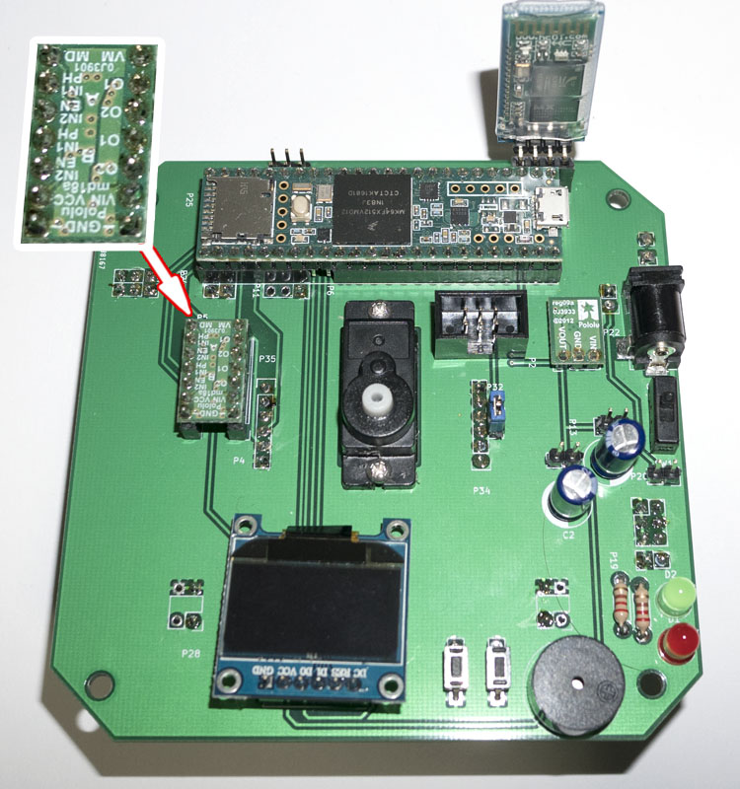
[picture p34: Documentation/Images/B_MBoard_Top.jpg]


# Join base & mainPCB

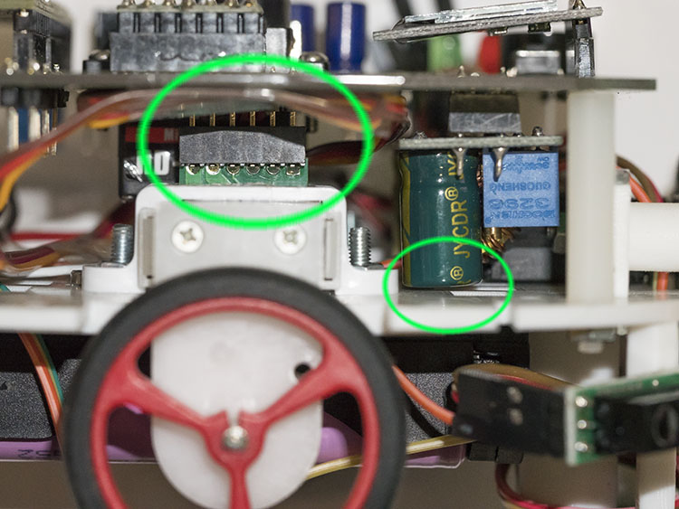
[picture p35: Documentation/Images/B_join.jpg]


# Connect pin headers

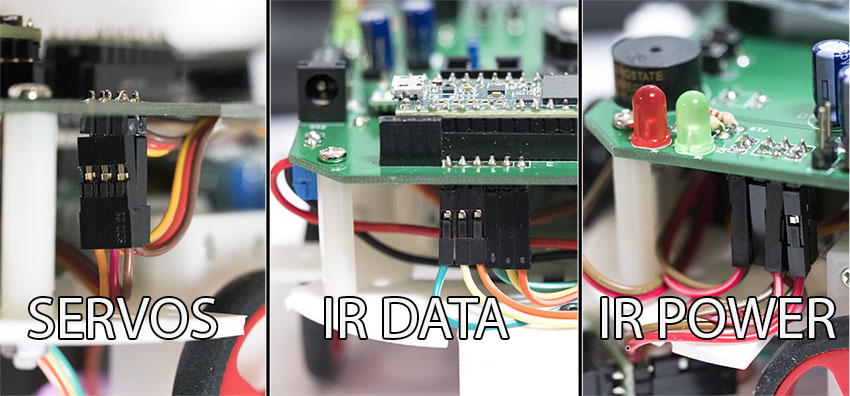
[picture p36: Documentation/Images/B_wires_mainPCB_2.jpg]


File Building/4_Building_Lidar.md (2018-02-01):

# Lidar PCB

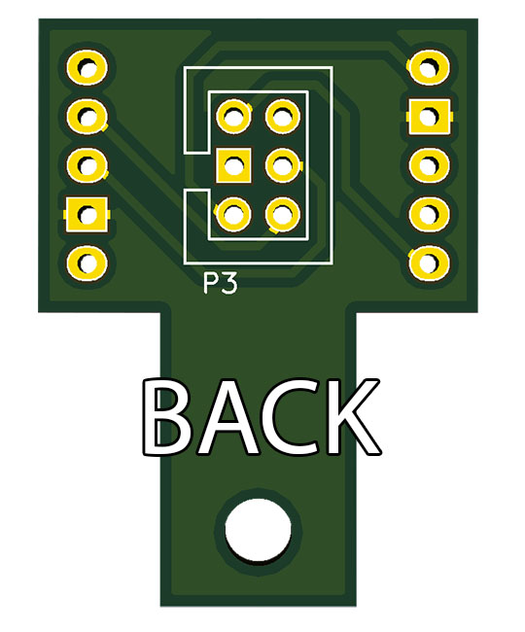
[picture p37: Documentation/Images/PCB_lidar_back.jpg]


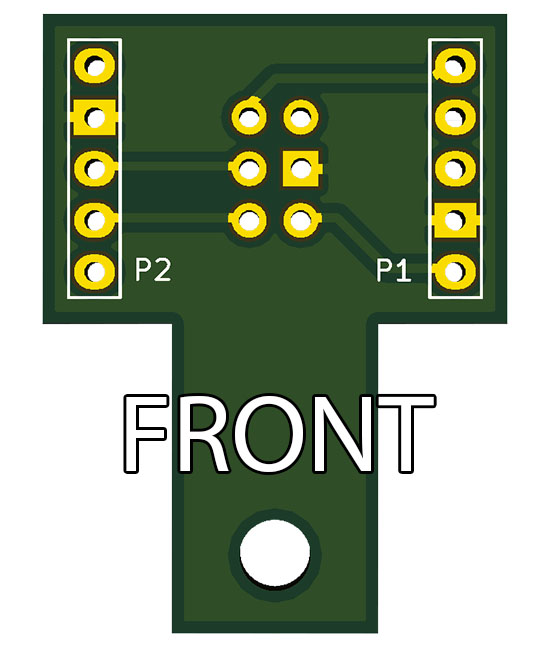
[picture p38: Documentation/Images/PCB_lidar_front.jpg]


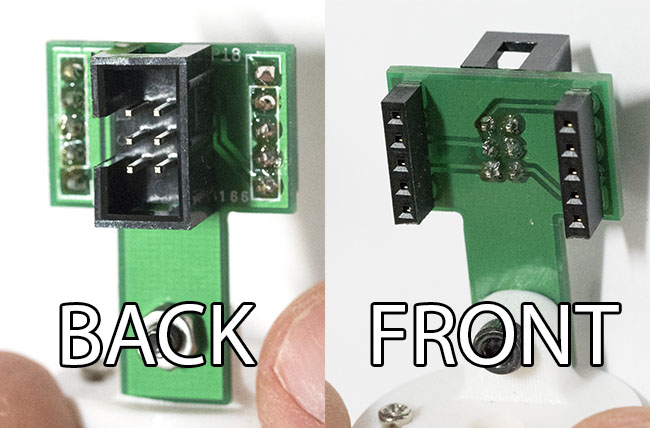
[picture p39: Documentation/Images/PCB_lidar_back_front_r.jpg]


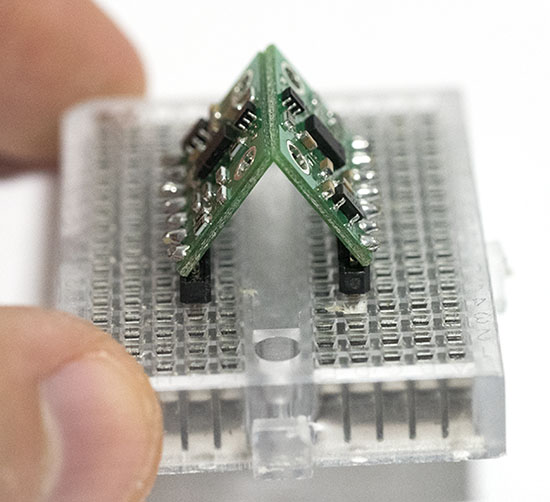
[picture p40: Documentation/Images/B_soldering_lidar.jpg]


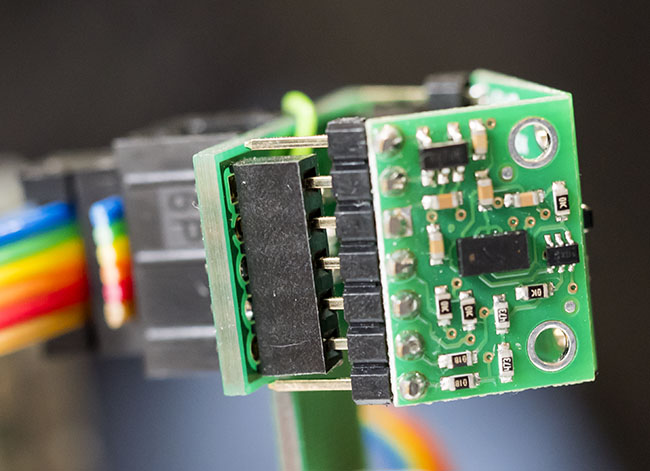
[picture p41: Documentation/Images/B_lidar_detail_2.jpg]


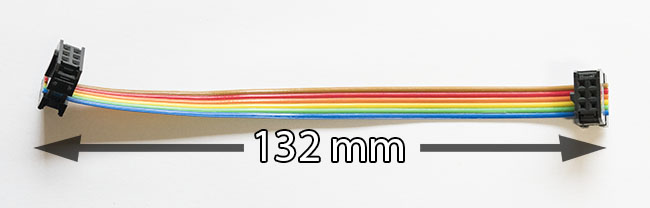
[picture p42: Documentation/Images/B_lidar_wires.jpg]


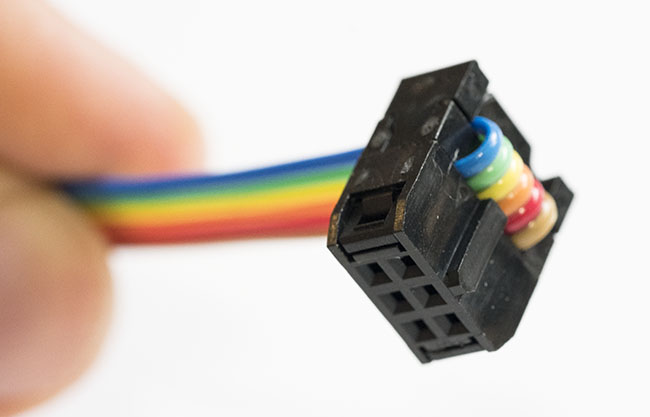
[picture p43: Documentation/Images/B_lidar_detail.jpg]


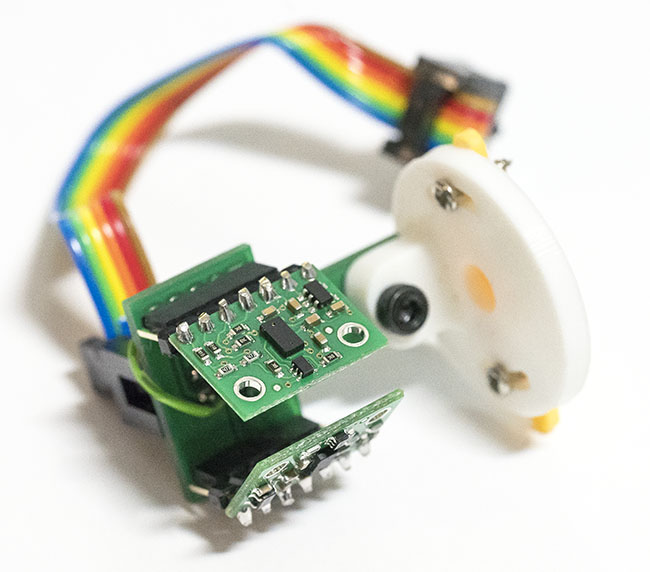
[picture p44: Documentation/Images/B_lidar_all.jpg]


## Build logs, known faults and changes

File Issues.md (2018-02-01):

* The next code doesn't read properly the lidar data on Linux (but works on Windows.)
anedubot\Code\Teensy\HardwareTest\two_lidars\two_lidars.ino

* I have to improve the stability camera and the Orange Pi support. The camera vibrates when the robot is moving around and it makes the image blurry

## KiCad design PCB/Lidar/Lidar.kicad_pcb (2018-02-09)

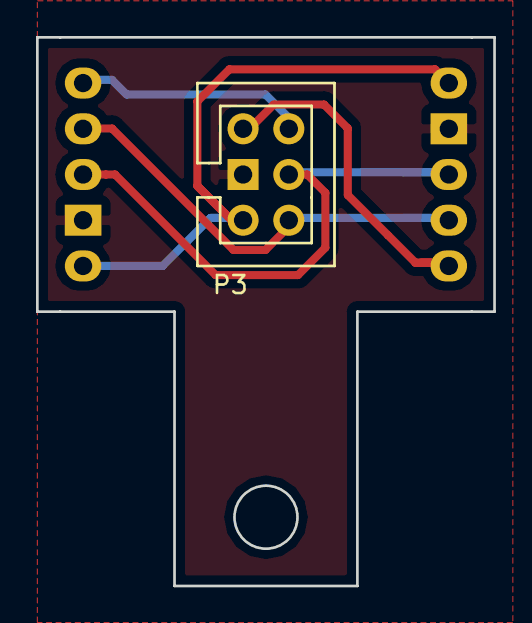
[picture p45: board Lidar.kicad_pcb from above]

Board: 2 copper layers, 25.4 x 30.5 mm, 3 parts (0 on the bottom side), 6 nets.

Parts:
P1: LIDAR_LEFT; Pin_Header_Straight_1x05
P2: LIDAR_RIGHT; Pin_Header_Straight_1x05
P3: CONN_02X03; Pin_Header_Straight_2x03

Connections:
GND: P1.2, P2.2, P3.4
LID_L_XSHUT: P1.5, P3.5
LID_R_XSHUT: P2.5, P3.6
LID_SCL: P1.4, P2.4, P3.1
LID_SDA: P1.3, P2.3, P3.3
LID_VIN: P1.1, P2.1, P3.2

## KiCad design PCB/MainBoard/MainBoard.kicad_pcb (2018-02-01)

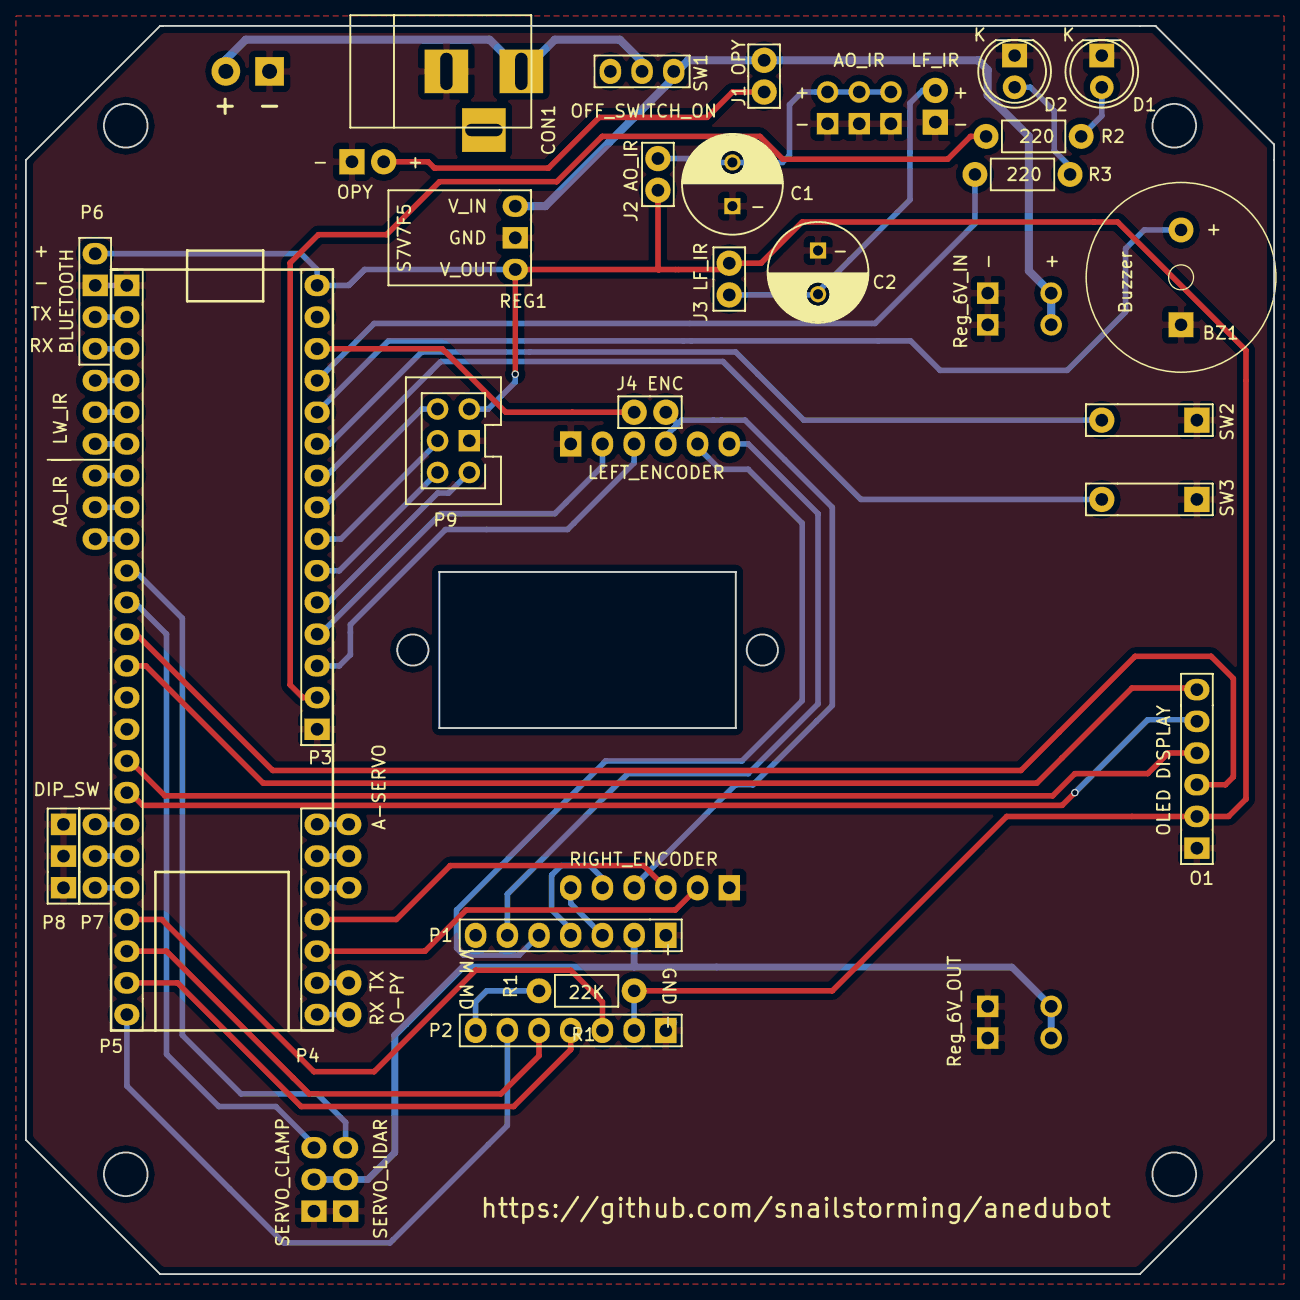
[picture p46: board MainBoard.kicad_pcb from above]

Board: 2 copper layers, 100.0 x 100.0 mm, 38 parts (0 on the bottom side), 55 nets.

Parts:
BZ1: Buzzer; Buzzer_15x7.5RM7.6
C1, C2: C; C_Radial_D8_L11.5_P3.5
CON1: BARREL_JACK
D1, D2: LED; LED-5MM
J1 OPY: CONN_RASPY; Pin_Header_Straight_1x02
J2 AO_IR, J3 LF_IR, J4 ENC: CONN_01X02; Pin_Header_Straight_1x02
O1: OLED DISPLAY; Pin_Header_Straight_1x06
P1, P2: MOTOR_DRIVER; Pin_Header_Straight_1x07
P4, P5: CONN_01X24; Pin_Header_Straight_1x24
P7: DIP_SW; Pin_Header_Straight_1x03
P8: DIP_SWITCH; Pin_Header_Straight_1x03
P9: CONN_02X03; Pin_Header_Straight_2x03
P10: AO_IR; Pin_Header_Straight_1x02
P11: IR_SENSORS; Pin_Header_Straight_2x03
P12: CONN_RASPY; Pin_Header_Straight_1x02
P13, P21: CONN_01X02; Pin_Header_Straight_1x02
P14: Reg_6V_IN; Pin_Header_Straight_2x02
P15: Reg_6V_OUT; Pin_Header_Straight_2x02
P16: LEFT_ENCODER; Pin_Header_Straight_1x06
P17: RIGHT_ENCODER; Pin_Header_Straight_1x06
P18: SERVO_CLAMP; Pin_Header_Straight_1x03
P19: SERVO_LIDAR; Pin_Header_Straight_1x03
P20: CONN_01X03; Pin_Header_Straight_1x03
P22: AO_IR | LW_IR; Pin_Header_Straight_1x10
R1, R2, R3: R; Resistor_Horizontal_RM7mm
REG1: S7V7F5; Pin_Header_Straight_1x03
SW1: OFF_SWITCH_ON; Pin_Header_Straight_1x03
SW2, SW3: SW_PUSH; Pin_Header_Straight_1x02

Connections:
+5V: J2 AO_IR.1, J3 LF_IR.1, O1.5, P2.6, P4.24, P9.2, P22.10, R1.1, REG1.1
+6V: P1.2, P15.1, P15.2, P18.2, P19.2
+BATT: CON1.1, P13.2, SW1.2
A_EN: P2.3, P5.3
A_PH: P2.2, P5.1
BUTTON_1: P4.19, SW2.2
BUTTON_2: P4.18, SW3.2
B_EN: P2.5, P5.4
B_PH: P2.4, P5.2
D0: O1.4, P5.13
D1: O1.3, P5.9
DC: O1.1, P5.12
GND: BZ1.2, C1.1, C2.1, CON1.2, D1.1, D2.1, O1.6, P1.1, P2.7, P4.10, P5.24, P8.1, P8.2, P8.3, P9.4, P10.1, P11.1, P11.3, P11.5, P12.2, P13.1, P14.3, P14.4, P15.3, P15.4, P16.6, P17.6, P18.3, P19.3, P22.9, REG1.2, SW2.1, SW3.1
GREEN_LED: P4.21, R3.1
L_ENC_A: P4.12, P16.4
L_ENC_B: P4.13, P16.5
unnamed: BZ1.1, D1.2, R2.2
unnamed: C2.2, J3 LF_IR.2, P10.2
unnamed: C1.2, J2 AO_IR.2, P11.2, P11.4, P11.6
unnamed: D2.2, R3.2
unnamed: P2.1, R1.2
unnamed: P4.2, P21.1
unnamed: P4.1, P21.2
unnamed: J1 OPY.1, P14.1, P14.2, REG1.3, SW1.1
unnamed: J1 OPY.2, P12.1
unnamed: P4.5, P20.3
unnamed: P4.6, P20.2
unnamed: P4.7, P20.1
unnamed: J4 ENC.1, P4.22
unnamed: P5.5, P7.1
unnamed: P5.6, P7.2
unnamed: P5.7, P7.3
unnamed: P5.16, P22.1
unnamed: P5.17, P22.2
unnamed: P5.18, P22.3
unnamed: P5.19, P22.4
unnamed: P5.20, P22.5
unnamed: P5.21, P22.6
unnamed: P5.22, P22.7
unnamed: P5.23, P22.8
unnamed: J4 ENC.2, P16.3, P17.3
O1_A: P1.6, P16.1
O1_B: P1.4, P17.2
O2_A: P1.5, P16.2
O2_B: P1.3, P17.1
RED_LED: P4.20, R2.1
RES: O1.2, P5.8
R_ENC_A: P4.4, P17.4
R_ENC_B: P4.3, P17.5
SCL: P4.17, P9.1
SDA: P4.16, P9.3
SERVO_CLAW_PWM: P5.15, P18.1
SERVO_LIDAR_PWM: P5.14, P19.1
X_LEFT: P4.15, P9.5
X_RIGHT: P4.14, P9.6

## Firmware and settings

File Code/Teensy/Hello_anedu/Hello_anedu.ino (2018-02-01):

#include <Adafruit_SSD1306.h>
#include "DRV8835_teensy3.h"
#include <Encoder.h>

#define LED_RED     13
#define LED_GREEN   23

#define BUZZER  22

#define BUTTON1     21
#define BUTTON2     20

#define OLED_MOSI   24
#define OLED_CLK    10
#define OLED_DC     11
#define OLED_CS     12
#define OLED_RESET  25

Adafruit_SSD1306 display(OLED_MOSI, OLED_CLK, OLED_DC, OLED_RESET, OLED_CS);
DRV8835 driveMotors(32, 30, 31, 29);
Encoder lwEnc(15, 14);
Encoder rwEnc(36, 35);

int menu_pos;
long endTicksLeft = lwEnc.read();
long endTicksRight = rwEnc.read();

void setup() {
  display.begin(SSD1306_SWITCHCAPVCC, 0x3C);
  driveMotors.init(23437);

  pinMode(LED_RED, OUTPUT);
  pinMode(LED_GREEN, OUTPUT);
  pinMode(BUTTON1, INPUT_PULLUP);
  pinMode(BUTTON2, INPUT_PULLUP);
  


  tone(BUZZER,2637,100);
  delay(150);
  tone(BUZZER,2637,100);
  delay(300);
  noTone(BUZZER);
  delay(500);
  
  digitalWrite(LED_GREEN, HIGH);
  digitalWrite(LED_RED, HIGH);
  delay(500);
  digitalWrite(LED_RED, LOW);
  delay(500);
  digitalWrite(LED_RED, HIGH);
  delay(500);
  digitalWrite(LED_RED, LOW);

  menu_pos = 1;

  display.clearDisplay();
  display.setTextSize(1);
  display.setTextColor(WHITE);
  display.setCursor(0,0);
  display.println("Hello, world!");
  display.setCursor(0,15);
  display.setTextColor(BLACK,WHITE);
  display.println("1. Motor test");
  display.setCursor(0,30);
  display.setTextColor(WHITE);
  display.println("2. Lidar test");
  display.display();

}

void loop() {
  
  if (digitalRead(BUTTON1) == LOW) {
    digitalWrite(LED_RED, HIGH);
    if (menu_pos == 1) {
      menu_pos = 2;
      display.clearDisplay();
      display.setTextSize(1);
      display.setTextColor(WHITE);
      display.setCursor(0,0);
      display.println("Hello, world!");
      display.setCursor(0,15);
      display.setTextColor(WHITE);
      display.println("1. Motor test");
      display.setCursor(0,30);
      display.setTextColor(BLACK,WHITE);
      display.println("2. Lidar test");
      display.display();      
    } else {
      menu_pos = 1;
      display.clearDisplay();
      display.setTextSize(1);
      display.setTextColor(WHITE);
      display.setCursor(0,0);
      display.println("Hello, world!");
      display.setCursor(0,15);
      display.setTextColor(BLACK,WHITE);
      display.println("1. Motor test");
      display.setCursor(0,30);
      display.setTextColor(WHITE);
      display.println("2. Lidar test");
      display.display(); 
    }
    delay(500);
  }
  else {
    digitalWrite(LED_RED, LOW);
  }
  if (digitalRead(BUTTON2) == LOW) {
    if (menu_pos == 1){

      endTicksLeft = lwEnc.read();
      endTicksRight = rwEnc.read();
      
      display.clearDisplay();
      display.setTextSize(1);
      display.setTextColor(WHITE);
      display.setCursor(0,0);
      display.println("MOTOR TEST");
      display.setCursor(0,15);
      display.println("Left Encoder");      
      display.setCursor(100,15);
      display.println(endTicksLeft);
      display.setCursor(0,30);
      display.println("Right Encoder");
      display.setCursor(100,30); 
      display.println(endTicksRight);
      display.display(); 
      
      driveMotors.setSpeeds(75,75);
      delay(500);
      driveMotors.setSpeeds(0,0);
      delay(500);
      
      endTicksLeft = lwEnc.read();
      endTicksRight = rwEnc.read();
      
      display.clearDisplay();
      display.setTextSize(1);
      display.setTextColor(WHITE);
      display.setCursor(0,0);
      display.println("MOTOR TEST");
      display.setCursor(0,15);
      display.println("Left Encoder");      
      display.setCursor(100,15);
      display.println(endTicksLeft);
      display.setCursor(0,30);
      display.println("Right Encoder");
      display.setCursor(100,30); 
      display.println(endTicksRight);
      display.display(); 

      delay(1000);
      
      driveMotors.setSpeeds(-75,-75);
      delay(500);
      driveMotors.setSpeeds(0,0);
      delay(500);

      endTicksLeft = lwEnc.read();
      endTicksRight = rwEnc.read();
      
      display.clearDisplay();
      display.setTextSize(1);
      display.setTextColor(WHITE);
      display.setCursor(0,0);
      display.println("MOTOR TEST");
      display.setCursor(0,15);
      display.println("Left Encoder");      
      display.setCursor(100,15);
      display.println(endTicksLeft);
      display.setCursor(0,30);
      display.println("Right Encoder");
      display.setCursor(100,30); 
      display.println(endTicksRight);
      display.display(); 

      delay(1000);      
      
      driveMotors.setSpeeds(75,-75);
      delay(500);
      driveMotors.setSpeeds(0,0);
      delay(500);

      endTicksLeft = lwEnc.read();
      endTicksRight = rwEnc.read();
      
      display.clearDisplay();
      display.setTextSize(1);
      display.setTextColor(WHITE);
      display.setCursor(0,0);
      display.println("MOTOR TEST");
      display.setCursor(0,15);
      display.println("Left Encoder");      
      display.setCursor(100,15);
      display.println(endTicksLeft);
      display.setCursor(0,30);
      display.println("Right Encoder");
      display.setCursor(100,30); 
      display.println(endTicksRight);
      display.display(); 

      delay(1000);
            
      driveMotors.setSpeeds(-75,75);
      delay(500);
      driveMotors.setSpeeds(0,0);
      endTicksLeft = lwEnc.read();
      endTicksRight = rwEnc.read();
      
      display.clearDisplay();
      display.setTextSize(1);
      display.setTextColor(WHITE);
      display.setCursor(0,0);
      display.println("MOTOR TEST");
      display.setCursor(0,15);
      display.println("Left Encoder");      
      display.setCursor(100,15);
      display.println(endTicksLeft);
      display.setCursor(0,30);
      display.println("Right Encoder");
      display.setCursor(100,30); 
      display.println(endTicksRight);
      display.display(); 

      delay(1000);

      display.clearDisplay();
      display.setTextSize(1);
      display.setTextColor(WHITE);
      display.setCursor(0,0);
      display.println("Hello, world!");
      display.setCursor(0,15);
      display.setTextColor(BLACK,WHITE);
      display.println("1. Motor test");
      display.setCursor(0,30);
      display.setTextColor(WHITE);
      display.println("2. Lidar test");
      display.display();  
    }
  }
}

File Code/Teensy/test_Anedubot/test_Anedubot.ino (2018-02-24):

// EDIT : Adafruit_SSD1306.h (73-75 line)
// FOLDER: arduino-1.X.X/hardware/teensy/avr/libraries/Adafruit_SSD1306
//       #define SSD1306_128_64
//   // #define SSD1306_128_32
//   //#define SSD1306_96_16


#include <Servo.h>
#include <Adafruit_SSD1306.h>
#include "DRV8835_teensy3.h"
#include <Encoder.h>

#include <Wire.h>
#include <VL53L0X.h>

#define pinRedLed     13
#define pinGreenLed   23
#define pinBuzzer     22
#define button1       21
#define button2       20
#define bluetooth     1
#define pinLeftLF     2
#define pinCenterLF   3
#define pinRightLF    4
#define pinLeftAO     5
#define pinCenterAO   6
#define pinRightAO    7
#define pinLidarServo 8
#define pinClampServo 9

#define OLED_MOSI   24
#define OLED_CLK    10
#define OLED_DC     11
#define OLED_CS     12
#define OLED_RESET  25

#define pinXshutL     17
#define pinXshutR     16

int dipPins[] = {26, 27, 28}; //DIP Switch Pins

Adafruit_SSD1306 display(OLED_MOSI, OLED_CLK, OLED_DC, OLED_RESET, OLED_CS);
DRV8835 driveMotors(32, 30, 31, 29);

Encoder lwEnc(15, 14);
Encoder rwEnc(36, 35);

VL53L0X sensorL;
VL53L0X sensorR;

int i;
int j;

int posLidar;
int posClamp;

bool sRedLed;
bool sGreenLed;
bool sServoClamp;

int sPinLeftLF;
int sPinCenterLF;
int sPinRightLF;
int sPinLeftAO;
int sPinCenterAO;
int sPinRightAO;

int robotId;

float dSensorL;
float dSensorR;

long endTicksLeft;
long endTicksRight;

int xPoint;
int yPoint;

int starttime;
int endtime;

Servo servoLidar;
Servo servoClamp;

void setup() {
  display.begin(SSD1306_SWITCHCAPVCC, 0x3D);
  display.clearDisplay();
  display.display();

//change VL53L0X address
  pinMode(pinXshutL, OUTPUT);
  pinMode(pinXshutR, OUTPUT);
  digitalWrite(pinXshutL, LOW);
  digitalWrite(pinXshutR, LOW);
  delay(500);
  Wire.begin();
  Serial.begin (9600);
  digitalWrite(pinXshutL, HIGH);
  delay(150);
  sensorL.init(true);
  delay(100);
  sensorL.setAddress((uint8_t)22);
  digitalWrite(pinXshutR, HIGH);
    delay(150);
  sensorR.init(true);
  delay(100);
  sensorR.setAddress((uint8_t)25);
//end change VL53L0X address  

// VL53L0X HIGH_SPEED mode
  sensorL.setMeasurementTimingBudget(20000);
  sensorR.setMeasurementTimingBudget(20000);

  driveMotors.init(23437);
  
  Serial.begin(9600);
  pinMode(pinRedLed, OUTPUT);
  pinMode(pinGreenLed, OUTPUT);
  pinMode(button1, INPUT_PULLUP);
  pinMode(button2, INPUT_PULLUP);

  for(i = 0; i<=2; i++){
    pinMode(dipPins[i], INPUT_PULLUP);      // sets the dipswitch pins as input
  }

  pinMode(pinLeftLF, INPUT);
  pinMode(pinCenterLF, INPUT);
  pinMode(pinRightLF, INPUT);
  pinMode(pinLeftAO, INPUT);
  pinMode(pinCenterAO, INPUT);
  pinMode(pinRightAO, INPUT);

  servoLidar.attach(pinLidarServo);
  servoClamp.attach(pinClampServo); 
  
  sRedLed = LOW;
  sGreenLed = LOW;


  delay(2000); //It is needed to show the text in Serial (throught USB) connection
  //WHO AM I
  for(i=0; i<=2; i++){
  j = (j << 1) | digitalRead(dipPins[i]);   // read the input pin
  }
  robotId = abs(j-7);
  Serial.print("I am :");
  Serial.println(robotId);
  
  display.clearDisplay();
  display.setTextSize(1);
  display.setTextColor(WHITE);
  display.setCursor(0,0);
  display.println("Hello, world!");
  display.setCursor(0,15);
  display.println("I am : Robot ");
  display.setCursor(80,15);
  display.println(robotId);
  display.display();


  //delay(1000);

  posLidar = 90;
  servoLidar.write(posLidar);

  posClamp = 70;
  servoClamp.write(posClamp);

  sServoClamp = HIGH;

  Serial.println("Test program");
  Serial.println(" 0. Print menu");
  Serial.println(" 1. Buzzer, leds, buttons & clamp servo");
  Serial.println(" 2. IR & encoders");
  Serial.println(" 3. Lidar servo");
  Serial.println(" 4. Motor calibration");
  Serial.println(" 5. Avoid Obstacles");
  Serial.println(" 6. Lidars");
  Serial.println(" 7. Mapping");
  Serial.println(" 8. Line follower");
  Serial.println(" 9. Lidar servo calibration");
}

void loop() {
  if (Serial.available() > 0) { 
    int inByte = Serial.read();
    
    switch (inByte) {
      case '0':
        Serial.println("Test program");
        Serial.println(" 0. Print menu");
        Serial.println(" 1. Buzzer, leds, buttons & clamp servo");
        Serial.println(" 2. IR & encoders");
        Serial.println(" 3. Lidar servo");
        Serial.println(" 4. Motor calibration");
        Serial.println(" 5. Avoid Obstacles");
        Serial.println(" 6. Lidars");
        Serial.println(" 7. Mapping");
        Serial.println(" 8. Line follower");
        Serial.println(" 9. Lidar servo calibration");
        
        break;
      
      case '1':
        tone(pinBuzzer,2637,100);
        delay(150);
        tone(pinBuzzer,2637,100);
        delay(300);
        tone(pinBuzzer,2637,100);
        delay(300);
        tone(pinBuzzer,2093,100);
        delay(100);
        tone(pinBuzzer,2637,100);
        delay(300);
        tone(pinBuzzer,3136,100);
        delay(550);
        tone(pinBuzzer,1568,100);
        delay(575);
        
        digitalWrite(pinRedLed, HIGH);
        digitalWrite(pinGreenLed, LOW);       
        delay(300);
        digitalWrite(pinRedLed, LOW);
        digitalWrite(pinGreenLed, HIGH); 
        delay(300);
        digitalWrite(pinRedLed, HIGH);
        digitalWrite(pinGreenLed, LOW);       
        delay(300);
        digitalWrite(pinRedLed, LOW);
        digitalWrite(pinGreenLed, HIGH); 
        delay(300);
        digitalWrite(pinRedLed, HIGH);
        digitalWrite(pinGreenLed, LOW);       
        delay(300);
        digitalWrite(pinRedLed, LOW);
        digitalWrite(pinGreenLed, HIGH); 
        delay(300);
        digitalWrite(pinGreenLed, LOW);       
        
        Serial.println("Start button test");
        starttime = millis();
        endtime = starttime;
        while ((endtime - starttime) <=10000) {        
          if (digitalRead(button1) == LOW) {
            tone(pinBuzzer,1568,100);

            posClamp = 160;
            servoClamp.write(posClamp);
            delay(150);
            posClamp = 166;
            servoClamp.write(posClamp);   
            delay(575);
          
          }
          if (digitalRead(button2) == LOW) {
            tone(pinBuzzer,2637,100);
            posClamp = 70;
            servoClamp.write(posClamp); 

            delay(575);
          }          
          
          delay(10);
          endtime = millis();
        }        
        Serial.println("End button test");

        break;
        
      case '2':
      Serial.println("Start IR & encoders test");
        starttime = millis();
        endtime = starttime;
        while ((endtime - starttime) <=20000) {        
          sPinLeftAO = digitalRead(pinLeftAO);
          sPinCenterAO = digitalRead(pinCenterAO);
          sPinRightAO = digitalRead(pinRightAO);

          sPinLeftLF = digitalRead(pinLeftLF);
          sPinCenterLF = digitalRead(pinCenterLF);
          sPinRightLF = digitalRead(pinRightLF);
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

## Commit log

2017-12-23 adding frame files
    [Base.scad, camera_support.fcstd, castor.scad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]
2017-12-23 adding lidar PCB
    [Lidar-B.Cu.gbr, Lidar-B.Mask.gbr, Lidar-B.SilkS.gbr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]
2017-12-23 adding 3D clamp
    [clamp.FCStd, clamp_old_version.FCStd]
2017-12-23 adding main pcb board
    [MainBoard-B.Cu.gbr, MainBoard-B.Mask.gbr, MainBoard-B.SilkS.gbr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]
2017-12-24 Adding lidar test code
2018-01-01 improving silks layers in PCB
    [MainBoard.kicad_pcb]
2018-01-01 Add PCB v2
    Add PCB with improved silk layers
    [MainBoard-B.Cu.gbr, MainBoard-B.Mask.gbr, MainBoard-B.SilkS.gbr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]
2018-01-01 Improving PCB silks layers
    [MainBoard-B.Cu.gbr, MainBoard-B.Mask.gbr, MainBoard-B.SilkS.gbr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]
2018-01-02 fix mistake in f.silk PCB
    [MainBoard.kicad_pcb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]
2018-01-02 Update PCB price
2018-01-03 Add stl files
    [Base.stl, camera_support.stl, clamp_servo_support.stl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]
2018-01-04 Correct a mistake in PCB silk layer
    [MainBoard.kicad_pcb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]
2018-01-05 Improve: Lidar PCB silk
    [Lidar.kicad_pcb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]
2018-01-06 Add Teensy code: Hello_anedu
2018-01-07 Change Red Led connection in main PCB
    [MainBoard-B.Cu.gbr, MainBoard-B.Mask.gbr, MainBoard-B.SilkS.gbr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]
2018-02-01 modify test anedu
    [Lidar.kicad_pcb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]
2018-02-04 Add lidarArrow
    [lidarArrow.FCStd, lidarArrow.stl]
2018-02-09 Change lidar PCB
    [Lidar-B.Cu.gbr, Lidar-B.Mask.gbr, Lidar-B.SilkS.gbr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]
